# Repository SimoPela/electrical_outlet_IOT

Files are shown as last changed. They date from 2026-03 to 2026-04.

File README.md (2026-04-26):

# Electrical Outlet IoT






ESP32-based environmental monitoring firmware plus a lightweight web dashboard for live MQTT telemetry.

The project is built around an ESP32 running ESP-IDF/FreeRTOS, collecting indoor environment data from multiple sensors (air quality, climate, particulate matter, light spectrum, motion, gas, and audio level), then publishing JSON payloads to MQTT. A Node.js dashboard subscribes to these topics and visualizes live values and trends.

<p align="center">
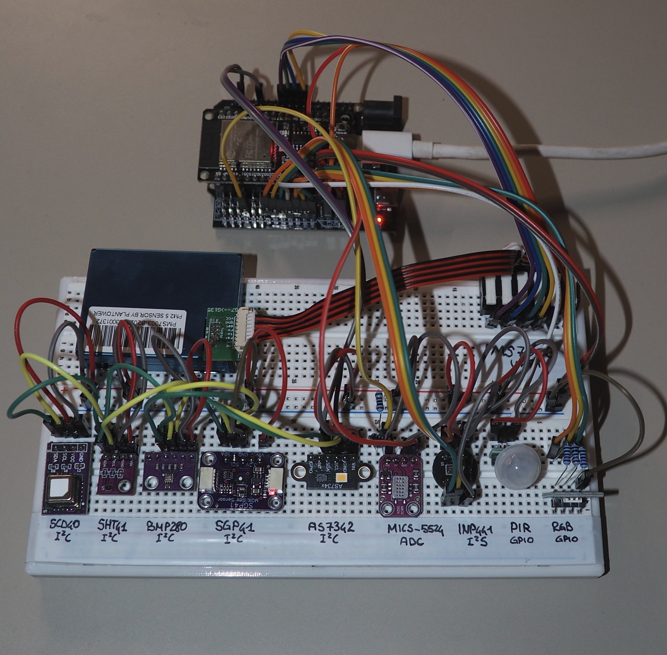
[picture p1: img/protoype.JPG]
Breadboard prototype with ESP32 and environmental sensors
  
</p>

---

## Features

- Multi-sensor acquisition on I2C, UART, I2S, ADC, and GPIO.
- FreeRTOS architecture with dedicated acquisition, audio, system, and communication tasks.
- Shared mutex-protected runtime state (`g_device_state`) with validity/fault flags and timestamps.
- Wi-Fi station mode with automatic reconnect and MQTT telemetry publishing.
- System health evaluation and alarm logic (motion, gas threshold, CO2 level bands).
- Real-time web dashboard (Express + Socket.IO + Chart.js) driven by MQTT messages.

---

## Hardware and Sensors

### Controller
- ESP32 DevKit-style board (`platformio.ini`: `board = esp32dev`, framework `espidf`).

### Sensor set
- `SCD40`: CO2, temperature, humidity (I2C)
- `SHT41`: temperature, humidity (I2C)
- `SGP41`: VOC/NOx indices (I2C, optional compensation from SHT41)
- `BMP280`: pressure, temperature (I2C)
- `AS7341`: 8-channel visible spectrum (I2C)
- `PMS7003`: PM1.0 / PM2.5 / PM10 (UART)
- `MiCS-5524`: gas raw voltage + estimated ppm (ADC)
- `AS312`: PIR motion sensor (GPIO)
- `INMP441`: noise level estimate in dB SPL (I2S)
- RGB status LED (GPIO)

### Default pinout
Defined in `lib/config/include/esp32_pinout.h`:

- I2C SDA/SCL: GPIO `21` / `22`
- PMS7003 TX/RX (sensor side): GPIO `16` / `17`
- PMS7003 SET/RESET: GPIO `4` / `5`
- PIR output: GPIO `27`
- I2S WS/SCK/SD: GPIO `25` / `26` / `33`
- MiCS-5524 ADC: GPIO `34`
- RGB LED R/G/B: GPIO `13` / `12` / `14`

---

## Firmware Architecture

### Boot flow
`app_main()` in `src/main.c` performs:

1. `device_state_init()`
2. `sensor_init_all()`
3. `network_app_init()` and wait for Wi-Fi connection
4. `mqtt_app_start()`
5. Task creation: `acquisition_task`, `audio_task`, `comm_task`, `system_task`

If sensor/network init fails, startup aborts.

### FreeRTOS tasks
Task definitions are configured in `include/task_config.h`.

| Task | Main role | Priority | Stack (words) | Loop period |
|---|---|---:|---:|---:|
| `acquisition_task` | Poll environmental sensors and update shared state | 2 | 4096 | 1000 ms |
| `audio_task` | Read INMP441 and update noise metrics | 2 | 4096 | 500 ms |
| `comm_task` | Publish MQTT system/environment/alarm payloads | 3 | 4096 | 100 ms |
| `system_task` | Evaluate health and alarm state | 4 | 4096 | 100 ms |

The firmware uses periodic polling instead of interrupt-driven sampling for most sensors.
`acquisition_task` runs every 1000 ms and checks per-sensor deadlines (for example 1000 ms, 2000 ms, 2500 ms, 5000 ms depending on the sensor). When a deadline is reached, it reads that sensor, updates local values, then commits a synchronized snapshot to the shared device state.
In parallel, `audio_task` handles the INMP441 capture pipeline at its own cadence, while `system_task` computes health/alarm flags and `comm_task` publishes MQTT payloads from a consistent state snapshot.

```mermaid
flowchart LR
    subgraph RTOS[FreeRTOS Runtime]
        ACQ["acquisition_task (1000 ms loop)\n- deadline-based polling\n- multi-sensor reads"]
        AUD["audio_task (500 ms loop)\n- INMP441 read\n- noise_db update"]
        SYS["system_task (100 ms loop)\n- health checks\n- alarm logic"]
        COM["comm_task (100 ms loop)\n- MQTT publish scheduler"]
    end

    DS[("g_device_state\n(mutex-protected shared snapshot)")]
    BRK["MQTT broker"]

    ACQ -->|"poll sensors + write measurements"| DS
    AUD -->|"write audio metrics"| DS
    SYS <-->|"read/write system flags"| DS
    COM -->|"read snapshot"| DS
    COM -->|"publish JSON payloads"| BRK
```

### Shared runtime state
`lib/device_state/include/device_state.h` defines:

- `g_device_state` (`device_state_t`): all sensor values, validity/fault flags, timestamps, connectivity flags, alarm status.
- `g_device_state_mutex`: protects shared state access.
- `g_sensor_driver_mutex`: serializes sensor driver access and restore operations.

### Health and alarms
Implemented in:
- `lib/health/src/health.c`
- `lib/alarm/src/alarm.c`

Current logic includes:
- degraded mode/system status based on validity/fault/freshness checks,
- motion alarm from PIR,
- gas alarm when MiCS-5524 estimated ppm is above threshold,
- CO2 qualitative level (`optimal`, `good`, `moderate`, `poor`, `very poor`, `critical`).

---

## MQTT Interface

Topic builders are implemented in `lib/mqtt/src/mqtt_topic.c`.

Published topics:

- `devices/<device_id>/telemetry/environment`
- `devices/<device_id>/status/system`
- `devices/<device_id>/event/alarm`

Payload builders are in `lib/mqtt/src/mqtt_payload.c`:

- **Environment payload**: CO2, temperatures, humidities, pressure, VOC/NOx, PM values, light channels, gas values, noise dB.
- **System payload**: `system_ok`, `degraded_mode`, `wifi_connected`, `mqtt_connected`, `status`.
- **Alarm payload**: `as312_alarm`, `mics5524_alarm`, `co2_alarm_level`.

---

## Repository Structure

```text
.
├── src/                    # app_main and FreeRTOS task implementations
├── include/                # task headers and timing/priority configuration
├── lib/
│   ├── config/             # app config template and ESP32 pin mapping
│   ├── sensor_init/        # centralized peripheral/sensor initialization
│   ├── device_state/       # shared state and mutexes
│   ├── network/            # Wi-Fi connection management
│   ├── mqtt/               # topic/payload/publish/client logic
│   ├── health/             # system health checks
│   ├── alarm/              # alarm decision logic
│   ├── inmp441/            # audio wrapper and dB estimate
│   └── ...                 # individual sensor drivers
├── server/                 # Node.js + Socket.IO live dashboard
├── scripts/                # build helper scripts (clangd/toolchain patching)
├── datasheet/              # sensor datasheets
└── platformio.ini          # PlatformIO environment
```

---

## Getting Started

### 1) Firmware (ESP32)

### Prerequisites
- [PlatformIO Core](https://platformio.org/install)
- ESP32 board connected over USB

### Configuration
1. Create/update `lib/config/include/app_config.h` using `lib/config/include/app_config_template.h`.
2. Set:
   - `APP_WIFI_SSID`
   - `APP_WIFI_PASSWORD`
   - `APP_MQTT_BROKER_URI`
   - `APP_MQTT_USERNAME`
   - `APP_MQTT_PASSWORD`
   - `APP_DEVICE_ID`
3. If needed, adjust GPIO mapping in `lib/config/include/esp32_pinout.h`.
4. Update serial upload settings in `platformio.ini` (`upload_port`, optionally `upload_speed`).

### Build, flash, monitor
```bash
pio run
pio run -t upload
pio device monitor -b 115200
```

Other useful commands:
```bash
# clean build
pio run -t clean
# erase flash
pio run -t erase
# generate compiledb database for IDE indexing
pio run -t compiledb
```

### 2) Dashboard server

The dashboard is located in `server/` and subscribes to MQTT topics, then forwards updates to browser clients via Socket.IO.

### Prerequisites
- Node.js 18+ recommended

### Setup
```bash
cd server
npm install
cp .env.example .env
```

Edit `.env`:
- `MQTT_BROKER_URL`
- `MQTT_USERNAME`
- `MQTT_PASSWORD`
- `PORT` (default `3000`)
- `ALARM_ON_MS` (temporary alarm display duration)

### Run
```bash
npm start
```

Open: `http://localhost:3000`

---

## Development Notes

- Build options and monitor/upload defaults are in `platformio.ini`.
- `scripts/update_clangd_toolchain.py` updates `.clangd` include sections after build for better IDE indexing.
- Sensor polling and publish intervals are centralized in `include/task_config.h`.
- Debug logs use ESP-IDF logging macros (`ESP_LOGE/W/I/D`).

---

## Security Notes

- Do not commit real Wi-Fi/MQTT credentials.
- Keep secrets only in local config files (`app_config.h`, `server/.env`) and exclude them from public history.

---

## License

This project is licensed under the Apache License 2.0 (see source headers).

## Authors

- Simone Pelascini
- Aurélien Bollin

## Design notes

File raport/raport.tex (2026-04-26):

\documentclass[11pt,a4paper]{article}
\usepackage[utf8]{inputenc}
\usepackage[T1]{fontenc}
\usepackage[english]{babel}
\usepackage{lmodern}
\usepackage{microtype}
\usepackage{geometry}
\usepackage{graphicx}
\usepackage[table]{xcolor}
\usepackage{booktabs}
\usepackage{longtable}
\usepackage{tabularx}
\usepackage{multirow}
\usepackage{hyperref}
\usepackage{enumitem}
\usepackage{tikz}
\usepackage{fancyhdr}
\usepackage{titlesec}
\usepackage{caption}
\usepackage{setspace}
\usepackage{mdframed}
\usepackage{array}
\usepackage{amsmath}
\usepackage{makecell}
\usepackage{seqsplit}

\usetikzlibrary{arrows.meta,positioning,shapes.geometric}

% --- Brand palette ---
\definecolor{bfhblue}{HTML}{1a3a5c}
\definecolor{bfhaccent}{HTML}{2d6a8f}
\definecolor{tablehdr}{HTML}{e8eef4}
\definecolor{lightgray}{HTML}{f5f7fa}
\definecolor{stategreen}{HTML}{d4edda}
\definecolor{stateyellow}{HTML}{fff3cd}
\definecolor{statered}{HTML}{f8d7da}
\definecolor{stategreentext}{HTML}{155724}
\definecolor{stateyellowtext}{HTML}{856404}
\definecolor{stateredtext}{HTML}{721c24}
\definecolor{infobox}{HTML}{e8f4fd}
\definecolor{infoborder}{HTML}{2d6a8f}

\geometry{margin=2.4cm, top=2.6cm, bottom=2.8cm, headheight=22pt}
\setlength{\parindent}{0pt}
\usetikzlibrary{arrows.meta,positioning,shapes.geometric,shapes.multipart}
%\setlength{\parskip}{6pt}
\hypersetup{
    colorlinks=true,
    linkcolor=bfhblue,
    urlcolor=bfhaccent,
    citecolor=bfhblue,
    pdftitle={RTOS Project Work -- Electrical Outlet IoT},
    pdfauthor={Simone Pelascini, Aurelien Bollin}
}

\captionsetup{font=small, labelfont={bf,color=bfhblue}}

% Section titles
\titleformat{\section}
    {\Large\bfseries\color{bfhblue}}
    {\thesection}{0.75em}{}
    [\vspace{-0.3em}{\color{bfhaccent}\titlerule[0.6pt]}]
\titleformat{\subsection}
    {\large\bfseries\color{bfhblue!85!black}}
    {\thesubsection}{0.6em}{}
\titleformat{\subsubsection}
    {\normalsize\bfseries\color{bfhblue!70!black}}
    {\thesubsubsection}{0.5em}{}
\titlespacing*{\section}{0pt}{1.8ex plus .2ex}{1.1ex plus .1ex}
\titlespacing*{\subsection}{0pt}{1.3ex plus .1ex}{0.7ex plus .1ex}

\setlist{itemsep=0.3ex, topsep=0.6ex}

% Info box style
\mdfdefinestyle{infoboxstyle}{
    backgroundcolor=infobox,
    linecolor=infoborder,
    linewidth=1.2pt,
    leftline=true, rightline=false, topline=false, bottomline=false,
    innerleftmargin=10pt, innerrightmargin=8pt,
    innertopmargin=6pt, innerbottommargin=6pt,
    skipabove=6pt, skipbelow=6pt
}

% Header / footer
\pagestyle{fancy}
\fancyhf{}
\fancyhead[L]{\small\color{bfhblue}\textbf{Electrical Outlet IoT}}
\fancyhead[R]{\small\color{gray}\nouppercase{\leftmark}}
\fancyfoot[C]{%
\small
Bern University of Applied Sciences \textbar{}
Engineering and Computer Science \textbar{}
Electrical Engineering and Information Technology
}
\renewcommand{\headrulewidth}{0.4pt}
\renewcommand{\headrule}{\hbox to\headwidth{\color{bfhaccent}\leaders\hrule height \headrulewidth\hfill}}

\fancypagestyle{plain}{%
  \fancyhf{}
  \fancyfoot[C]{%
  \small
  Bern University of Applied Sciences \textbar{}
  Engineering and Computer Science \textbar{}
  Electrical Engineering and Information Technology
  }
  \renewcommand{\headrulewidth}{0pt}
}

% Helpers
\newcommand{\rowhdr}{\rowcolor{tablehdr}}
\newcommand{\stateImpl}{\cellcolor{stategreen}\textcolor{stategreentext}{\textbf{implemented}}}
\newcommand{\statePartial}{\cellcolor{stateyellow}\textcolor{stateyellowtext}{\textbf{partial}}}
\newcommand{\stateOpen}{\cellcolor{statered}\textcolor{stateredtext}{\textbf{open}}}

% ============================================================
\begin{document}

% ---------- Title page ----------
\begin{titlepage}
    \centering
    \vspace*{0.15cm}
    {\color{bfhblue}\rule{\textwidth}{2.2pt}}
    \vspace{0.55cm}

    {\Large\color{bfhaccent}Bern University of Applied Sciences\par}
    {\normalsize Engineering and Computer Science\par}
    {\normalsize Electrical Engineering and Information Technology\par}

    \vspace{1.2cm}
    {\Huge\bfseries\color{bfhblue}RTOS Project Work\par}
    \vspace{0.45cm}
    {\LARGE\color{bfhblue!80!black}Electrical Outlet IoT\par}
    \vspace{0.35cm}
    {\large Environmental monitoring node on ESP32 with FreeRTOS and MQTT\par}

    \vspace{1.6cm}
    \IfFileExists{../img/protoype.JPG}{%
        %
        \par\vspace{0.3em}
        {\small\color{gray}\textit{Breadboard prototype of the sensor node.}}
    }{%
        \fbox{\parbox{0.60\textwidth}{\centering\vspace{2.2cm}\texttt{../img/protoype.JPG} not found\vspace{2.2cm}}}%
    }

    \vfill
    {\large\textbf{Authors:} Simone Pelascini \quad\textbar\quad Aur\'elien Bollin\par}
    \vspace{0.6cm}
    {\large\textbf{Date:} \today\par}
    \vspace{1cm}
    {\color{bfhblue}\rule{\textwidth}{2pt}}
\end{titlepage}

\cleardoublepage
\pagenumbering{arabic}
\setcounter{page}{1}

\onehalfspacing
\tableofcontents
\newpage

% ============================================================
\section{Summary}
\vspace{10pt}

The \textbf{Electrical Outlet IoT} project is an ESP32-based environmental monitoring node designed to
be integrated into a standard wall-outlet form factor. The motivation behind this project is the growing
demand for \textbf{ambient air quality monitoring} and \textbf{occupancy-aware automation} in residential
and commercial buildings. Poor indoor air quality, driven by CO\textsubscript{2} accumulation,
volatile organic compounds (VOC), particulate matter (PM), and combustible gas, is a largely invisible
health risk. Existing commercial solutions are either too expensive, closed-source, or limited to a single
measurement type.

\vspace{5pt}

This project addresses that gap by combining nine sensors on a single node,
connected to a local MQTT broker for real-time telemetry. The firmware is built on \textit{PlatformIO},
\textit{ESP-IDF}, and \textit{FreeRTOS}, making use of four concurrent tasks that coordinate through
a \textbf{mutex-protected global state structure}. Sensor data is published as JSON payloads
and consumed by a companion Node.js dashboard that renders live charts via \textit{Chart.js}
and pushes updates to browsers via \textit{Socket.IO}.

\vspace{5pt}

The current repository documents breadboard bring-up, firmware architecture, runtime
characterisation, and the web-dashboard edge. The form-factor integration into an actual outlet housing
is left as a future step.

% ============================================================
\section{System Context}
\subsection{Hardware}
\vspace{5pt}

The sensor node is built around an \textbf{ESP32 dual-core 240~MHz} microcontroller (Espressif
\texttt{esp32dev} target). It communicates with nine sensors over five distinct interfaces.
Table~\ref{tab:sensors} summarises the complete sensor inventory.

{\footnotesize
\setlength{\tabcolsep}{4pt}
\renewcommand{\arraystretch}{1.1}

\rowcolors{2}{lightgray}{white}
\setlength\LTleft{0pt}
\begin{longtable}{@{}p{2.3cm}p{2.8cm}p{6cm}p{1.4cm}p{2.5cm}@{}}
\caption{Complete sensor inventory used by the ESP32 node.\label{tab:sensors}}\\
\rowhdr
\textbf{Sensor} & \textbf{Measured quantity} & \textbf{Physical value} & \textbf{Bus} & \textbf{Driver} \\
\midrule
\endhead
SCD40        & CO\textsubscript{2}, T, RH & Concentration, temperature, humidity & I\textsuperscript{2}C & Direct ESP-IDF \\
SHT41        & Temperature, humidity & High-precision T \& RH & I\textsuperscript{2}C & esp-idf-lib \\
SGP41        & VOC, NOx              & Gas indices 0--500 (Sensirion algorithm) & I\textsuperscript{2}C & Custom + GIA \\
BMP280       & Pressure, temperature & Atmospheric P \& T & I\textsuperscript{2}C & esp-idf-lib \\
AS7341       & Light spectrum        & 8-channel F1--F8 basic counts & I\textsuperscript{2}C & k0i05/esp\_as7341 \\
PMS7003      & Particulate matter    & PM1.0, PM2.5, PM10 [\textmu g/m\textsuperscript{3}] & UART & Custom wrapper \\
MiCS-5524    & Combustible gas       & Voltage [V], heuristic CO [ppm] & ADC & Custom \\
AS312        & PIR motion            & Motion detected (boolean) & GPIO & Custom \\
INMP441      & Ambient noise         & Sound pressure level [dB~SPL] & I\textsuperscript{2}S & Custom DSP \\
\bottomrule
\end{longtable}
\rowcolors{2}{}{}
}

\newpage

\subsection{System actors and data paths}
\vspace{5pt}

The system involves the following actors:
\begin{itemize}[leftmargin=*]
    \item \textbf{Sensor node}: ESP32 (\texttt{esp32dev}), firmware in \texttt{src/} and \texttt{lib/}.
          Samples all sensors on software-defined deadlines, aggregates readings into a shared
          in-memory state, and transmits them via Wi-Fi.
    \item \textbf{Wi-Fi / TCP}: the node connects as a Wi-Fi station; all MQTT traffic flows over
          a standard TCP connection to the broker.
    \item \textbf{MQTT broker}: any standard broker (e.g.\ Mosquitto) reachable on the LAN.
          Credentials and URI are configured in \texttt{lib/config/include/app\_config.h}.
    \item \textbf{Node.js dashboard}: an optional \texttt{server/} application that subscribes to
          all device topics and renders live charts in the browser via Socket.IO and Chart.js.
    \item \textbf{Third-party consumers}: any MQTT subscriber can access the JSON payloads
          independently of the dashboard.
\end{itemize}

\vspace{5pt}
\subsection{MQTT topics}
\vspace{5pt}

All publications follow the hierarchy \texttt{devices/\textless device\_id\textgreater /}
where \texttt{device\_id} is set by \texttt{\seqsplit{APP\_DEVICE\_ID}}:

\begin{itemize}[leftmargin=*]
    \item \texttt{telemetry/environment} (QoS~0) --- full sensor snapshot:
          CO\textsubscript{2}, T, RH from SCD40 and SHT41, atmospheric pressure, VOC/NOx indices,
          PM1.0/2.5/10, 8-channel light array, gas voltage and ppm, noise level in dB~SPL.
          Published every \textbf{1~s}.
    \item \texttt{\seqsplit{status/system}} (QoS~1, retain) --- system health flags:
          \texttt{\seqsplit{system\_ok}}, \texttt{\seqsplit{degraded\_mode}}, \texttt{\seqsplit{wifi\_connected}},
          \texttt{\seqsplit{mqtt\_connected}}. Published every \textbf{10~s} and immediately on reconnect.
    \item \texttt{\seqsplit{event/alarm}} (QoS~1) --- event-driven alert:
          \texttt{\seqsplit{as312\_alarm}} (motion), \texttt{\seqsplit{mics5524\_alarm}} (gas threshold exceeded),
          \texttt{\seqsplit{co2\_alarm\_level}} (IDA-inspired 6-level classification).
          Published only on the \textbf{rising edge} of each alarm flag.
\end{itemize}

\vspace{5pt}
\subsection{Web dashboard}
\vspace{5pt}

The companion dashboard runs on Node.js (\texttt{server/public/server.js}) and uses the
\texttt{\seqsplit{express}}, \texttt{\seqsplit{mqtt}}, \texttt{\seqsplit{socket.io}}, and \texttt{\seqsplit{dotenv}} packages. It subscribes
to the wildcard patterns \texttt{\seqsplit{devices/+/telemetry/environment}},
\texttt{\seqsplit{devices/+/status/system}}, and \texttt{\seqsplit{devices/+/event/alarm}}, merges incoming payloads
into a per-device state object, and forwards it to all connected browsers in real time.
Configuration is via a \texttt{.env} file (\texttt{\seqsplit{MQTT\_BROKER\_URL}}, optional credentials, \texttt{\seqsplit{PORT}}).

\newpage

% ============================================================
\section{Requirements}\label{sec:requirements}
\vspace{10pt}

Requirements are written from the user perspective and are traceable to implementation files.
The \textbf{State} column uses colour coding:
\colorbox{stategreen}{\textcolor{stategreentext}{implemented}},
\colorbox{stateyellow}{\textcolor{stateyellowtext}{partial}}, or
\colorbox{statered}{\textcolor{stateredtext}{open}}.

{\footnotesize
\setlength{\tabcolsep}{4pt}
\renewcommand{\arraystretch}{1.1}

\rowcolors{2}{lightgray}{white}
\setlength\LTleft{0pt}
\begin{longtable}{@{}>{\bfseries}p{0.9cm}p{11.6cm}p{3.0cm}@{}}
\caption{System requirements and current implementation status.\label{tab:requirements}}\\
\rowhdr
\multicolumn{1}{@{}l}{\textbf{ID}} & \textbf{Requirement (user perspective)} & \textbf{State} \\
\midrule
\endhead
R1 & The system shall boot, initialise all peripherals, create four FreeRTOS tasks, and reach a
     fully operational state without a fatal error within 20~s of power-on. & \stateImpl \\
R2 & The system shall connect to the configured Wi-Fi network within 15~s; on disconnect it shall
     retry up to \texttt{APP\_WIFI\_MAX\_RETRY} times automatically. & \stateImpl \\
R3 & The system shall publish a JSON environment payload to the MQTT broker at least every 1~s
     and a system-status payload every 10~s when connected. & \stateImpl \\
R4 & The system shall publish an alarm event payload on the rising edge of a motion or gas alarm,
     without missing edges caused by task jitter. & \stateImpl \\
R5 & All concurrent accesses to \texttt{g\_device\_state} shall be serialised by a FreeRTOS
     mutex (\texttt{g\_device\_state\_mutex}) with no unbounded blocking. & \stateImpl \\
R6 & All nine integrated sensors shall be polled within their specified deadlines without one
     slow sensor blocking another. & \stateImpl \\
R7 & The system shall report an estimated ambient noise level (\texttt{noise\_db}) in dB~SPL;
     absolute accuracy relative to a calibrated sound-level meter is not guaranteed without
     field calibration of \texttt{INMP441\_SPL\_OFFSET\_DB}. & \statePartial \\
R8 & Stack high-water mark and heap usage shall be logged and reported for all tasks over at
     least 10~minutes of continuous operation. & \stateImpl \\
R9 & Automated unit tests shall cover MQTT payload builders and sensor supervision logic. & \stateOpen \\
R10 & The system shall attempt automatic sensor restoration (re-initialisation and recovery) after
      a detected sensor crash, with bounded retries and fault reporting if recovery fails. & \stateOpen \\
\bottomrule
\end{longtable}
\rowcolors{2}{}{}
}

\newpage

% ============================================================
\section{Design}
\subsection{Boot sequence}
\vspace{5pt}

At startup, \texttt{app\_main} (in \texttt{src/main.c}) executes the following ordered steps.
All critical steps abort the system on failure; non-critical sensor failures are logged as
warnings and allow the system to continue in degraded mode.

\begin{enumerate}[leftmargin=*, label=\textbf{\arabic*.}]
    \item \textbf{\texttt{device\_state\_init()}} --- zero-initialises \texttt{g\_device\_state}
          and creates the two FreeRTOS mutexes (\texttt{g\_device\_state\_mutex} and
          \texttt{g\_sensor\_driver\_mutex}).
    \item \textbf{\texttt{sensor\_init\_all()}} --- initialises hardware peripherals in order:
          ADC unit~1, I\textsuperscript{2}S channel, I\textsuperscript{2}C bus, UART~2, then
          each sensor driver. Critical peripherals abort on failure; sensors warn and continue.
    \item \textbf{\texttt{network\_app\_init()}} --- initialises NVS, netif, Wi-Fi driver, and
          starts the connection; registers event handlers for \texttt{WIFI\_EVENT} and
          \texttt{IP\_EVENT}.
    \item \textbf{\texttt{\seqsplit{network\_app\_wait\_until\_connected(15000)}}} --- blocks up to 15~s
          waiting for \texttt{\seqsplit{APP\_WIFI\_CONNECTED\_BIT}}; aborts if the bit is not set.
    \item \textbf{\texttt{mqtt\_app\_start()}} --- creates the ESP-IDF MQTT client, registers
          the event handler, and starts the client task.
    \item \textbf{Task creation} --- \texttt{xTaskCreate} is called for each of the four tasks;
          any allocation failure aborts immediately.
\end{enumerate}

\newpage

\subsection{FreeRTOS task architecture}

The firmware is decomposed into four independent FreeRTOS tasks. All tasks use
\texttt{vTaskDelayUntil} for deterministic loop periods and \texttt{xSemaphoreTake} /
\texttt{xSemaphoreGive} for exclusive access to the shared state. Table~\ref{tab:tasks} summarises
the static parameters.

{\footnotesize
\setlength{\tabcolsep}{4pt}
\renewcommand{\arraystretch}{1.1}

\rowcolors{2}{lightgray}{white}
\setlength\LTleft{0pt}
\begin{longtable}{@{}p{3.1cm}p{7.6cm}ccp{2.0cm}@{}}
\caption{Static configuration of the four FreeRTOS tasks.\label{tab:tasks}}\\
\rowhdr
\textbf{Task} & \textbf{Responsibility} & \textbf{Pri.} & \textbf{Stack (w)} & \textbf{Period} \\
\midrule
\endhead
\texttt{acquisition\_task} & Polls all sensors on individual software deadlines; writes measured
  values, validity flags, and fault flags into \texttt{g\_device\_state} under the mutex. & 2 & 4096 & 1000~ms \\
\texttt{audio\_task} & DMA-reads one audio block from the INMP441 via I\textsuperscript{2}S,
  computes AC-RMS SPL, and updates \texttt{noise\_db} in the shared state. & 2 & 4096 & 500~ms \\
\texttt{comm\_task} & Snapshots the shared state and drives the MQTT publish schedule:
  environment telemetry at 1~s, system status at 10~s, and alarm events on rising edge. & 3 & 4096 & 100~ms \\
\texttt{system\_task} & Reads the shared state snapshot, evaluates per-sensor health checks
  (staleness, fault, validity) and alarm logic, then writes derived system flags back. & 4 & 4096 & 100~ms \\
\bottomrule
\end{longtable}
\rowcolors{2}{}{}
}

\vspace{5pt}
\begin{mdframed}[style=infoboxstyle]
\textbf{Design pattern --- local state before commit.}
Each task maintains a task-local state structure initialised to zero. Sensor readings and flags are
written to this local copy first; only when a consistent update is ready is the mutex acquired and
the global \texttt{g\_device\_state} updated in a single block-copy. This minimises the critical
section duration and avoids partially-updated state being observed by other tasks.
\end{mdframed}

\subsection{Sensor polling intervals}

Sensors inside \texttt{\seqsplit{acquisition\_task}} are polled on independent software timers derived from
\texttt{\seqsplit{xTaskGetTickCount()}}. Each sensor deadline is checked at every 1000~ms task tick; the
sensor is read only when \texttt{now - last\_read \(\geq\) interval}. This means a single slow
sensor (e.g.\ PMS7003) does not delay faster ones (e.g.\ AS312).

\vspace{8pt}

{\footnotesize
\setlength{\tabcolsep}{4pt}
\renewcommand{\arraystretch}{1.1}

\noindent
\captionof{table}{Sensor polling intervals and interfaces used by the firmware.\label{tab:polling_intervals}}
\begin{tabularx}{\textwidth}{@{}lXrr@{}}
\toprule
\rowhdr
\textbf{Sensor} & \textbf{Physical quantity} & \textbf{Interface} & \textbf{Interval} \\
\midrule
AS312  & PIR motion                         & GPIO                          & 1000~ms \\
MiCS-5524 & Combustible gas (CO heuristic)  & ADC                           & 1000~ms \\
SGP41  & VOC index, NOx index               & I\textsuperscript{2}C         & 1000~ms \\
AS7341 & 8-channel light spectrum           & I\textsuperscript{2}C         & 1000~ms \\
SHT41  & Temperature, humidity              & I\textsuperscript{2}C         & 2000~ms \\
BMP280 & Atmospheric pressure               & I\textsuperscript{2}C         & 2000~ms \\
SCD40  & CO\textsubscript{2}, temperature, humidity & I\textsuperscript{2}C  & 2500~ms \\
PMS7003 & PM1.0, PM2.5, PM10               & UART                          & 5000~ms \\
INMP441 & Noise level (dB SPL)             & I\textsuperscript{2}S (audio\_task) & 500~ms \\
\bottomrule
\end{tabularx}
}

\newpage

\subsection{System supervision and alarm logic}

\texttt{system\_task} implements two independent modules:

\textbf{Health module} (\texttt{lib/health/}): after a 45~s cold-start window, each sensor
is checked for three conditions: (1) the validity flag is \texttt{false}, (2) the fault flag is
\texttt{true}, or (3) the timestamp age exceeds a per-sensor timeout (45~s for all sensors).
Any failing check sets \texttt{degraded\_mode = true} and the sensor-specific \texttt{degraded\_*}
flag.

\textbf{Alarm module} (\texttt{lib/alarm/}): three independent sub-checks evaluate
(1)~motion from the AS312 PIR, (2)~gas concentration from MiCS-5524 against a 5000~ppm threshold,
and (3)~CO\textsubscript{2} from SCD40 classified into six levels (Optimal / Good / Moderate /
Poor / Very Poor / Critical) following IDA and ASHRAE~62.1-inspired thresholds.

\subsection{System context diagram}
\vspace{5pt}

\begin{figure}[!htbp]
\centering
\begin{tikzpicture}[
    scale=0.82,
    transform shape,
    node distance=9mm and 18mm,
    task/.style={
        draw=bfhblue!70!black,
        rounded corners=2pt,
        align=center,
        minimum width=58mm,
        minimum height=10mm,
        fill=lightgray,
        font=\small
    },
    state/.style={
        draw=bfhblue!70!black,
        cylinder,
        shape border rotate=90,
        aspect=0.25,
        align=center,
        minimum width=42mm,
        minimum height=13mm,
        fill=white,
        font=\small
    },
    ext/.style={
        draw=bfhaccent!80!black,
        rounded corners=2pt,
        align=center,
        minimum width=32mm,
        minimum height=10mm,
        fill=lightgray,
        font=\small
    },
    arrow/.style={
        -{Latex[length=2.2mm]},
        thick,
        color=bfhblue!75!black
    },
    label/.style={
        font=\scriptsize,
        fill=white,
        inner sep=1.5pt,
        text=bfhaccent!80!black
    }
]

% Sensors block
\node[ext] (sensors)
{\textbf{Sensors}\\[-1pt]\scriptsize 9 sensors};

% Tasks
\node[task, below right=18mm and 30mm of sensors] (acq)
{\texttt{acquisition\_task}\\[-1pt]\scriptsize 1000~ms prio 2};

\node[task, below=18mm of acq] (audio)
{\texttt{audio\_task}\\[-1pt]\scriptsize 500~ms prio 2};

\node[task, below=18mm of audio] (system)
{\texttt{system\_task}\\[-1pt]\scriptsize 100~ms prio 4};

\node[task, below=18mm of system] (comm)
{\texttt{comm\_task}\\[-1pt]\scriptsize 100~ms prio 3};

% Shared state and MQTT
\node[state, right=35mm of audio] (devstate)
{\texttt{g\_device\_state}\\[-1pt]\scriptsize mutex-protected};

\node[ext, below right=18mm and 38mm of comm] (mqtt)
{\textbf{MQTT broker}\\[-1pt]\scriptsize Wi-Fi / TCP};

% Connections
\draw[arrow] (sensors.east) -- node[label, above]
{GPIO/I\textsuperscript{2}C/ADC/UART/I\textsuperscript{2}S}
(acq.west);

\draw[arrow] (acq.east) -- node[label, above]
{poll sensors + write measurements}
(devstate.north west);

\draw[arrow] (audio.east) -- node[label, above]
{write audio metrics}
(devstate.west);

\draw[arrow] (system.east) -- node[label, above]
{read/write system flags}
(devstate.south west);

\draw[arrow] (devstate.south) |- node[label, near start, right]
{read snapshot}
(comm.east);

\draw[arrow] (comm.east) -- node[label, below]
{publish JSON payloads}
(mqtt.west);

\end{tikzpicture}

\caption{System context diagram showing sensors, FreeRTOS tasks, the mutex-protected shared state,
and the MQTT broker used for publishing telemetry, status, and alarm messages.}
\end{figure}

\newpage

\subsection{UML task interaction diagram}

\begin{figure}[!htbp]
\centering
\IfFileExists{../img/uml_4task.png}{%
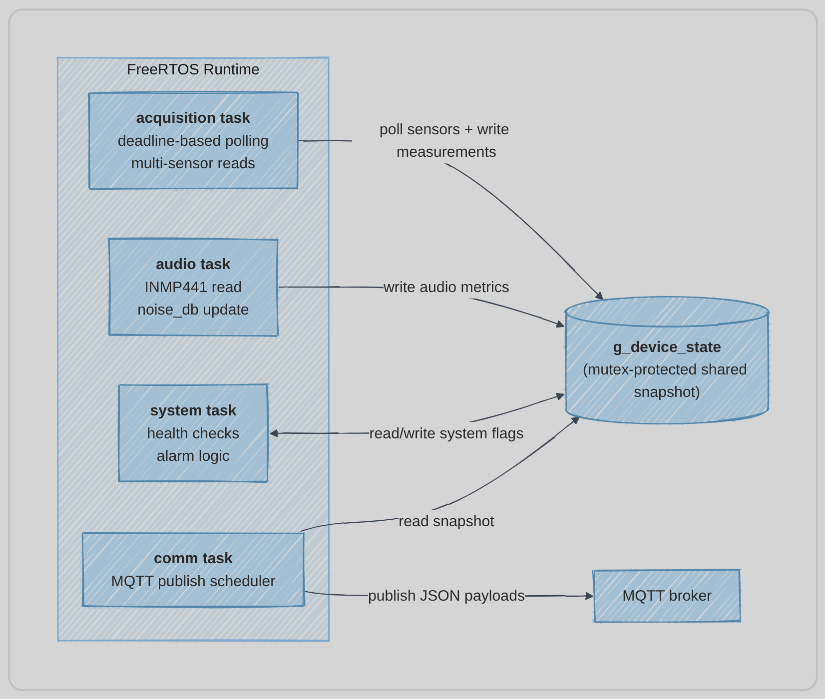
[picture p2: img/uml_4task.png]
    %
}{%
    \fbox{\parbox{0.88\textwidth}{\centering\vspace{1.8cm}
    \texttt{../img/uml\_4task.png} not found\vspace{1.8cm}}}%
}
\caption{UML activity/sequence diagram of the four FreeRTOS tasks and their interactions
with \texttt{g\_device\_state} and the MQTT client.}
\end{figure}

\subsection{Acquisition polling flow}

\begin{figure}[!htbp]
\centering
\begin{tikzpicture}[
    scale=0.82,
    transform shape,
    node distance=6mm,
    proc/.style={draw=bfhblue!65, rounded corners=2pt, align=center,
                 minimum width=58mm, minimum height=7mm, fill=white, font=\small},
    dec/.style={draw=bfhaccent, diamond, aspect=2.3, align=center,
                inner sep=1pt, fill=lightgray, font=\small},
    arrow/.style={-{Latex[length=1.8mm]}, thick, color=bfhblue!70!black}
]
\node[proc] (loop) {\textbf{Task tick} (every 1000~ms via \texttt{vTaskDelayUntil})};
\node[dec, below=of loop] (due) {Sensor deadline\\ elapsed?};
\node[proc, below=of due] (read) {Read sensor $\rightarrow$ local state};
\node[proc, below=of read] (flag) {Update validity / fault flags};
\node[proc, below=of flag] (commit) {Acquire mutex $\rightarrow$ copy to \texttt{g\_device\_state} $\rightarrow$ release};
\node[proc, right=22mm of read] (skip) {Skip (next tick)};

\draw[arrow] (loop) -- (due);
\draw[arrow] (due) -- node[left, font=\scriptsize] {yes} (read);
\draw[arrow] (read) -- (flag);
\draw[arrow] (flag) -- (commit);
\draw[arrow] (commit.east) -| (skip.south);
\draw[arrow] (due.east) -- node[above, font=\scriptsize] {no} (skip.north);
\draw[arrow] (skip.north east) -- ++(6mm,0) |- (loop.east);
\end{tikzpicture}
\caption{Deadline-driven polling inside \texttt{acquisition\_task}: each sensor has its own
independent timer; skipped sensors do not block the loop.}
\end{figure}

\newpage

% ============================================================
\section{Runtime Statistics}\label{sec:runtime}

\subsection{Methodology}
\vspace{5pt}

Runtime measurements were collected from the ESP32 serial log using the helper functions
\texttt{logTaskStackHeapUsage()} and \texttt{logTaskAlive()}, defined in
\texttt{src/task\_config.c}. Each task logs its own stack high-water mark and the system-wide
heap state every \textbf{10~s} of wall-clock time. The measurements span approximately
\textbf{10~minutes} of continuous operation under normal conditions (all sensors active,
Wi-Fi connected, MQTT publishing running). Raw data is archived in
\texttt{raport/project\_info/stack\_heap.txt}.

Stack usage percentage is computed as:
\[
\text{Stack Usage} = \frac{\text{words used (high-water mark)}}{\text{stack allocated (words)}} \times 100\%
\]
where \emph{words used} = allocated $-$ high-water mark remaining (reported by
\texttt{\seqsplit{uxTaskGetStackHighWaterMark()}}; 1~word~= 4~bytes on ESP32).

\subsection{Stack usage per task}

\vspace{5pt}
{\footnotesize
\setlength{\tabcolsep}{4pt}
\renewcommand{\arraystretch}{1.1}

\rowcolors{2}{lightgray}{white}
\setlength\LTleft{0pt}
\begin{longtable}{@{}p{3.0cm}p{1.5cm}p{2.5cm}p{2.5cm}p{2.5cm}p{2.5cm}@{}}
\caption{Measured stack usage per FreeRTOS task over the runtime window.\label{tab:stack_usage}}\\
\rowhdr
\textbf{Task} & \textbf{Pri.} &
\makecell[c]{\textbf{Stack}\\\textbf{alloc. (w)}} &
\makecell[c]{\textbf{Stack used}\\\textbf{(HWM, w)}} &
\makecell[c]{\textbf{Usage}\\\textbf{(\%)}} &
\makecell[c]{\textbf{Avg. CPU}\\\textbf{(\%)}} \\
\midrule
\endhead
\texttt{acquisition\_task} & 2 & 4096 & 2532 & 61.8\% & n/m \\
\texttt{audio\_task}       & 2 & 4096 & 2124 & 51.9\% & n/m \\
\texttt{comm\_task}        & 3 & 4096 & 2812 & 68.7\% & n/m \\
\texttt{system\_task}      & 4 & 4096 & 2352 & 57.4\% & n/m \\
\bottomrule
\end{longtable}
\rowcolors{2}{}{}
}
{\small\textit{n/m = not measured (FreeRTOS runtime stats counter not enabled in this build).}}

\medskip
\begin{mdframed}[style=infoboxstyle]
\textbf{Stack analysis.}
The highest consumer is \texttt{comm\_task} (68.7\%), followed by \texttt{acquisition\_task}
(61.8\%). Even the worst case leaves \textbf{1284~words (5136~bytes) of free stack headroom}
on \texttt{comm\_task}, well above the ESP-IDF recommended minimum of 512~bytes. No stack
overflow was observed during the measurement window. All four stacks are sized safely at the
current feature set; if JSON payload building or additional sensors are added,
\texttt{comm\_task} should be monitored first.
\end{mdframed}

\newpage

\subsection{Heap usage over time}

The heap figures below are system-wide (MALLOC\_CAP\_8BIT pool, total $\approx$~290~KB).
``Min free'' is the all-time minimum free heap reported by
\texttt{heap\_caps\_get\_minimum\_free\_size}, which is the most conservative safety margin.

\vspace{5pt}
{\footnotesize
\setlength{\tabcolsep}{4pt}
\renewcommand{\arraystretch}{1.1}

\rowcolors{2}{lightgray}{white}
\setlength\LTleft{0pt}
\begin{longtable}{@{}p{2.6cm}p{2.3cm}p{2.3cm}p{2.5cm}p{1.5cm}p{3.5cm}@{}}
\caption{System heap usage at three measurement windows.\label{tab:heap}}\\
\rowhdr
\textbf{Window} &
\textbf{Used (B)} &
\textbf{Free (B)} &
\textbf{Min free (B)} &
\textbf{Usage} &
\textbf{Notes} \\
\midrule
\endhead
$\sim$10~s  & 107\,460 & 183\,116 & 176\,968 & 37.0\% & Post-boot steady state \\
$\sim$1~min & 107\,452 & 183\,124 & 176\,968 & 37.0\% & Stable; marginal drift \\
$\sim$10~min & 107\,432 & 183\,144 & 176\,968 & 37.0\% & Stable baseline \\
Peak (transient) & 108\,992 & 181\,584 & 176\,968 & 37.5\% & Acquisition spike \\
\bottomrule
\end{longtable}
\rowcolors{2}{}{}

}

\vspace{5pt}
\begin{mdframed}[style=infoboxstyle]
\textbf{Heap analysis.}
Heap usage is highly stable at approximately \textbf{37\%} of the total $\approx$290~KB pool,
leaving a comfortable \textbf{63\% free} ($\approx$183~KB) during steady-state operation.
The minimum-free-ever figure of \textbf{176\,968~B} ($\approx$173~KB) confirms that even
transient allocation peaks (up to 108\,992~B used, observed periodically during
\texttt{acquisition\_task} sensor reads) do not threaten memory safety.
Importantly, the baseline heap usage \emph{decreased} slightly over 10~minutes (from 107\,460~B
to 107\,432~B), indicating that there are \textbf{no measurable memory leaks} over the
observation window.
\end{mdframed}

\newpage

% ============================================================
\section{File Structure}
\vspace{10pt}

The repository follows the PlatformIO convention with a \texttt{src/} entry point, a
\texttt{lib/} folder for reusable modules, and a top-level \texttt{include/} for headers
shared across tasks. Each library module lives in its own subdirectory with an \texttt{include/}
header folder and a \texttt{src/} implementation folder, making cross-compilation units and
Doxygen generation straightforward.

\vspace{5pt}
{\footnotesize
\setlength{\tabcolsep}{4pt}
\renewcommand{\arraystretch}{1.1}

\rowcolors{2}{lightgray}{white}
\begin{longtable}{@{}p{3.5cm}p{12.2cm}@{}}
\caption{Repository file structure and module responsibilities.\label{tab:file_structure}}\\
\rowhdr
\textbf{Path} & \textbf{Purpose} \\
\midrule
\endhead
\texttt{src/} & Application entry point (\texttt{main.c}) and the four FreeRTOS task implementations:
  \texttt{acquisition\_task.c}, \texttt{audio\_task.c}, \texttt{comm\_task.c},
  \texttt{system\_task.c}. Also contains \texttt{task\_config.c} (stack/heap logging helpers)
  and \texttt{idf\_component.yml} (managed component manifest). \\
\texttt{include/} & Shared task headers (\texttt{*\_task.h}); \texttt{task\_config.h} defining
  stack sizes, task priorities, sensor polling intervals, and MQTT publish cadences. \\
\texttt{lib/config/} & \texttt{app\_config\_template.h} (Wi-Fi, MQTT, QoS, device ID constants)
  and \texttt{esp32\_pinout.h} (GPIO/peripheral pin assignments). \\
\texttt{lib/device\_state/} & Global \texttt{g\_device\_state} struct and the two FreeRTOS
  mutexes; all sensor values, timestamps, validity/fault flags, and system flags. \\
\texttt{lib/network/} & Wi-Fi station init (\texttt{network\_app.c}): NVS, netif, event handlers,
  reconnect logic, and the connection-ready event group. \\
\texttt{lib/mqtt/} & Four modules: \texttt{mqtt\_app} (client lifecycle), \texttt{mqtt\_topic}
  (topic string builders), \texttt{mqtt\_payload} (JSON serialisers),
  \texttt{mqtt\_publish} (high-level publish API). \\
\texttt{lib/sensor\_init/} & Peripheral bring-up: \texttt{adc\_init}, \texttt{i2s\_init},
  \texttt{uart\_init} (individual units), and \texttt{sensor\_init} (orchestrates all). \\
\texttt{lib/} (drivers) & One folder per sensor: \texttt{scd40}, \texttt{sht41}, \texttt{sgp41},
  \texttt{bmp280}, \texttt{as7341}, \texttt{pms7003}, \texttt{mics5524}, \texttt{as312},
  \texttt{inmp441}. Plus \texttt{health} (supervision), \texttt{alarm} (event logic),
  \texttt{rgbled} (status LED). \\
\texttt{lib/sgp41/include/} & Also contains Sensirion's BSD-3 Gas Index Algorithm header
  (\texttt{sensirion\_gas\_index\_algorithm.h}). \\
\texttt{server/} & Node.js dashboard: \texttt{public/server.js} (MQTT subscriber +
  Socket.IO relay), \texttt{app.js}, \texttt{index.html}, \texttt{style.css},
  \texttt{package.json}. \\
\texttt{scripts/} & \texttt{update\_clangd\_toolchain.py}: PlatformIO post-build hook that
  patches \texttt{.clangd} with the correct ESP-IDF include paths for IDE support. \\
\texttt{platformio.ini} & Build configuration: \texttt{esp32dev} target, ESP-IDF framework,
  4~MB flash, 115200~baud monitor, post-build extra script. \\
\texttt{raport/} & This report (\texttt{raport.tex}), the BFH template PDF,
  and \texttt{project\_info/} with raw measurement logs. \\
\bottomrule
\end{longtable}
\rowcolors{2}{}{}

}

\newpage
% ============================================================
\section{User Manual}
\vspace{10pt}

\begin{mdframed}[style=infoboxstyle]
\textbf{Prerequisite:} the ESP32 has already been flashed with the firmware.
You need a Wi-Fi network and an MQTT broker (e.g.\ Mosquitto) reachable on the same LAN.
\end{mdframed}

\subsection{Step 1 --- Configure credentials}

Open \texttt{lib/config/include/app\_config.h} and fill in your values:

\begin{verbatim}
#define APP_WIFI_SSID        "YourNetworkSSID"
#define APP_WIFI_PASSWORD    "YourNetworkPassword"
#define APP_MQTT_BROKER_URI  "mqtt://192.168.1.10"   // broker IP
#define APP_DEVICE_ID        "esp32_node_01"         // unique ID
\end{verbatim}

Leave \texttt{APP\_MQTT\_USERNAME} and \texttt{APP\_MQTT\_PASSWORD} empty if your broker has no
authentication. Rebuild and re-flash after editing this file.

\subsection{Step 2 --- Flash and monitor}

From the repository root, run:

\begin{verbatim}
# Build, upload, and open serial monitor (115200 baud)
pio run -t upload && pio device monitor -b 115200
\end{verbatim}

If the serial port is not detected automatically, add \texttt{upload\_port = /dev/ttyUSB0}
(or the appropriate port) to \texttt{platformio.ini}.

\subsection{Step 3 --- Verify boot sequence}

Watch the serial output. A successful startup prints, in order:

\begin{enumerate}[leftmargin=*, label=\textbf{\arabic*.}]
    \item \texttt{[MAIN] System booting...}
    \item \texttt{[MAIN] Sensors initialized successfully}
    \item \texttt{[MAIN] Wi-Fi connected successfully}
    \item \texttt{[MAIN] Starting MQTT}
    \item \texttt{MQTT\_APP: MQTT client started}
    \item \texttt{[MAIN] All tasks started}
\end{enumerate}

If any step fails, the system prints an error and calls \texttt{abort()}. Check credentials
(\texttt{app\_config.h}), broker reachability (ping from the same subnet), and GPIO wiring.

\newpage
\subsection{Step 4 --- Subscribe to MQTT topics}

Use any MQTT client to verify the data stream. Example with \texttt{mosquitto\_sub}:

\begin{verbatim}
# All topics for this device
mosquitto_sub -h 192.168.1.10 -t "devices/esp32_node_01/#" -v

# Environment telemetry only
mosquitto_sub -h 192.168.1.10 \
  -t "devices/esp32_node_01/telemetry/environment" -v
\end{verbatim}

You should see a new JSON payload roughly every second on the environment topic.

\subsection{Step 5 --- Start the web dashboard (optional)}

\begin{verbatim}
cd server
npm install                    # first run only
cp .env.example .env           # create local config
\end{verbatim}

Edit \texttt{.env} and set \texttt{MQTT\_BROKER\_URL=mqtt://192.168.1.10} (and
\texttt{PORT} if needed), then:

\begin{verbatim}
npm start
\end{verbatim}

Open \texttt{http://localhost:3000} (or the configured port) in a browser. Live charts for all
sensor channels update automatically via Socket.IO.

\subsection{Troubleshooting}

\begin{itemize}[leftmargin=*]
    \item \textbf{Wi-Fi fails}: verify SSID/password in \texttt{app\_config.h}; check that the
          access point uses WPA2-PSK.
    \item \textbf{MQTT fails}: ping the broker from the LAN; ensure \texttt{APP\_MQTT\_BROKER\_URI}
          starts with \texttt{mqtt://} and uses the correct IP and port (default 1883).
    \item \textbf{Sensor missing from payload}: check wiring against \texttt{esp32\_pinout.h};
          the \texttt{degraded\_mode} flag in \texttt{status/system} will be \texttt{true}
          after 45~s if a sensor stops responding.
    \item \textbf{Noise level seems wrong}: the \texttt{INMP441\_SPL\_OFFSET\_DB} constant in
          \texttt{\seqsplit{lib/inmp441/src/inmp441\_w.c}} can be adjusted. Compare the reported
          \texttt{noise\_db} against a calibrated sound-level meter in a known environment and
          set \texttt{offset = L\_meter - L\_firmware}.
\end{itemize}

\newpage
% ============================================================
\section{Version control}
\vspace{10pt}
{\footnotesize
\setlength{\tabcolsep}{4pt}
\renewcommand{\arraystretch}{1.1}

\rowcolors{2}{lightgray}{white}
\setlength\LTleft{0pt}
\begin{longtable}{@{}p{1.0cm}p{2.2cm}p{10.6cm}p{1.5cm}@{}}
\caption{Document revision history.\label{tab:version_history}}\\
\rowhdr
\textbf{Ver.} & \textbf{Date} & \textbf{Description} & \textbf{Author} \\
\midrule
\endhead
0.1 & 2026-03-18 & Initial RTOS template alignment; basic structure and task overview. & S.\ / A. \\
0.2 & 2026-03-21 & Sensor integration notes; first version of requirements table. & S.\ / A. \\
0.3 & 2026-04-06 & Architecture refresh: context diagram, acquisition flowchart, TODO metrics. & S.\ / A. \\
0.4 & 2026-04-06 & Full English report; layout refresh; MQTT/dashboard/scripts sync with repo. & S.\ / A. \\
0.5 & 2026-04-24 & Runtime statistics filled with measured stack/heap values from 10-min logs. & S.\ / A. \\
1.0 & 2026-04-24 & Final report: sensor table, analysis boxes, improved design section,
                   UML diagram, extended user manual, troubleshooting guide. & S.\ / A. \\
\bottomrule
\end{longtable}
\rowcolors{2}{}{}
}
\vspace{1.2em}
\noindent\textit{Firmware and tools are licensed under the Apache~2.0 License unless noted
otherwise in individual file headers. The Sensirion Gas Index Algorithm is licensed under
BSD~3-Clause.}

\end{document}

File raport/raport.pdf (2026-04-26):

## Bern University of Applied Sciences

Engineering and Computer Science Electrical Engineering and Information Technology

# RTOS Project Work

## Electrical Outlet IoT

Environmental monitoring node on ESP32 with FreeRTOS and MQTT


Breadboard prototype of the sensor node.

Authors: Simone Pelascini | Aurélien Bollin

Date: April 26, 2026

Electrical Outlet IoT | Contents

## Contents

1 Summary | 2
2 System Context | 2
3 Requirements | 4
4 Design | 5
5 Runtime Statistics | 9
6 File Structure | 11
7 User Manual | 12
8 Version control | 14
Bern University of Applied Sciences | Engineering and Computer Science | Electrical Engineering and
Information Technology

Electrical Outlet IoT | 2 System Context

## 1 Summary

The Electrical Outlet IoT project is an ESP32-based environmental monitoring node designed to be integrated into a standard wall-outlet form factor. The motivation behind this project is the growing demand for ambient air quality monitoring and occupancy-aware automation in residential and commercial buildings. Poor indoor air quality, driven by CO2 accumulation, volatile organic compounds (VOC), particulate matter (PM), and combustible gas, is a largely

invisible health risk. Existing commercial solutions are either too expensive, closed-source, or limited to a single measurement type.

This project addresses that gap by combining nine sensors on a single node, connected to a local MQTT broker for real-time telemetry. The firmware is built on PlatformIO, ESP-IDF, and FreeRTOS, making use of four concurrent tasks that coordinate through a mutex-protected global state structure. Sensor data is published as JSON payloads and consumed by a companion Node.js dashboard that renders live charts via Chart.js and pushes updates to browsers via Socket.IO.

The current repository documents breadboard bring-up, firmware architecture, runtime characterisation, and the web-dashboard edge. The form-factor integration into an actual outlet housing is left as a future step.

## 2 System Context

### 2.1 Hardware

The sensor node is built around an ESP32 dual-core 240 MHz microcontroller (Espressif esp32dev target). It communicates with nine sensors over five distinct interfaces. Table 1

summarises the complete sensor inventory.

Table 1: Complete sensor inventory used by the ESP32 node.

Sensor | Measured quan-
tity
Physical value | Bus | Driver
SCD40 | CO2, T, RH | Concentration, temperature, humidity | 2C I | Direct ESP-IDF
SHT41 | Temperature, humidity | High-precision T & RH | 2C I | esp-idf-lib
SGP41 | VOC, NOx | Gas indices 0–500 (Sensirion algorithm) | I 2C | Custom + GIA
BMP280 | Pressure, tempera-ture | Atmospheric P & T | 2C I | esp-idf-lib
AS7341 | Light spectrum | 8-channel F1–F8 basic counts | I 2C | k0i05/esp_as7341
PMS7003 | Particulate matter | PM1.0, PM2.5, PM10 [µg/m³ ] | UART | Custom wrapper
MiCS-5524 | Combustible gas | Voltage [V], heuristic CO [ppm] | ADC | Custom
AS312 | PIR motion | Motion detected (boolean) | GPIO | Custom
INMP441 | Ambient noise | Sound pressure level [dB SPL] | 2S I | Custom DSP

Electrical Outlet IoT | 2 System Context

### 2.2 System actors and data paths

The system involves the following actors:

- Sensor node: ESP32 (esp32dev), firmware in src/ and lib/. Samples all sensors on software-

defined deadlines, aggregates readings into a shared in-memory state, and transmits them via Wi-Fi.

- Wi-Fi / TCP: the node connects as a Wi-Fi station; all MQTT traffic flows over a standard

TCP connection to the broker.

- MQTT broker: any standard broker (e.g. Mosquitto) reachable on the LAN. Credentials and

URI are configured in lib/config/include/app_config.h.

- Node.js dashboard: an optional server/ application that subscribes to all device topics and renders live charts in the browser via Socket.IO and Chart.js.
- Third-party consumers: any MQTT subscriber can access the JSON payloads independently of the dashboard.

### 2.3 MQTT topics

All publications follow the hierarchy devices/<device_id>/ where device_id is set by APP_DEV

ICE_ID:

- telemetry/environment (QoS 0) — full sensor snapshot: CO2, T, RH from SCD40 and SHT41, atmospheric pressure, VOC/NOx indices, PM1.0/2.5/10, 8-channel light array, gas

voltage and ppm, noise level in dB SPL. Published every 1 s.

- status/system (QoS 1, retain) — system health flags: system_ok, degraded_mode, wifi_co

nnected, mqtt_connected. Published every 10 s and immediately on reconnect.

- event/alarm (QoS 1) — event-driven alert: as312_alarm (motion), mics5524_alarm (gas threshold exceeded), co2_alarm_level (IDA-inspired 6-level classification). Published only on

the rising edge of each alarm flag.

### 2.4 Web dashboard

The companion dashboard runs on Node.js (server/public/server.js) and uses the express, m

qtt, socket.io, and dotenv packages. It subscribes to the wildcard patterns devices/+/teleme

try/environment, devices/+/status/system, and devices/+/event/alarm, merges incoming payloads into a per-device state object, and forwards it to all connected browsers in real time. Configuration is via a .env file (MQTT_BROKER_URL, optional credentials, PORT).

Electrical Outlet IoT | 3 Requirements

## 3 Requirements

Requirements are written from the user perspective and are traceable to implementation files.
The State column uses colour coding: | implemented | , | partial | , or | open | .

Table 2: System requirements and current implementation status.

ID | Requirement (user perspective) | State
R1 | The system shall boot, initialise all peripherals, create four FreeRTOS tasks, and reach a fully operational state without a fatal error within 20 s of power-on. | implemented
R2 | The system shall connect to the configured Wi-Fi network within 15 s; on disconnect it shall retry up to APP_WIFI_MAX_RETRY times automatically. | implemented
R3 | The system shall publish a JSON environment payload to the MQTT broker at least every 1 s and a system-status payload every 10 s when connected. | implemented
R4 | The system shall publish an alarm event payload on the rising edge of a motion or gas alarm, without missing edges caused by task jitter. | implemented
R5 | All concurrent accesses to g_device_state shall be serialised by a FreeRTOS mutex (g_device_state_mutex) with no unbounded blocking. | implemented
R6 | All nine integrated sensors shall be polled within their specified deadlines without one slow sensor blocking another. | implemented
R7 | The system shall report an estimated ambient noise level (noise_db) in dB SPL; absolute accuracy relative to a calibrated sound-level meter is not guaranteed without field calibration of INMP441_SPL_OFFSET_DB. | partial
R8 | Stack high-water mark and heap usage shall be logged and reported for all tasks over at least 10 minutes of continuous operation. | implemented
R9 | Automated unit tests shall cover MQTT payload builders and sensor supervision logic. | open
R10 | The system shall attempt automatic sensor restoration (re-initialisation and re-covery) after a detected sensor crash, with bounded retries and fault reporting if recovery fails. | open

Electrical Outlet IoT | 4 Design

## 4 Design

### 4.1 Boot sequence

At startup, app_main (in src/main.c) executes the following ordered steps. All critical steps

abort the system on failure; non-critical sensor failures are logged as warnings and allow the system to continue in degraded mode.

### 1. device_state_init() — zero-initialises g_device_state and creates the two FreeRTOS

mutexes (g_device_state_mutex and g_sensor_driver_mutex).

2. sensor_init_all() — initialises hardware peripherals in order: ADC unit 1, I²S channel, I²C

bus, UART 2, then each sensor driver. Critical peripherals abort on failure; sensors warn and

continue.

3. network_app_init() — initialises NVS, netif, Wi-Fi driver, and starts the connection; registers event handlers for WIFI_EVENT and IP_EVENT.

### 4. network_app_wait_until_connected(15000) — blocks up to 15 s waiting for APP_WIFI_CO

NNECTED_BIT; aborts if the bit is not set.

### 5. mqtt_app_start() — creates the ESP-IDF MQTT client, registers the event handler, and

starts the client task.

6. Task creation — xTaskCreate is called for each of the four tasks; any allocation failure aborts immediately.

Electrical Outlet IoT | 4 Design

### 4.2 FreeRTOS task architecture

The firmware is decomposed into four independent FreeRTOS tasks. All tasks use vTaskDelayUntil for deterministic loop periods and xSemaphoreTake / xSemaphoreGive for exclusive access to the

shared state. Table 3 summarises the static parameters.

Table 3: Static configuration of the four FreeRTOS tasks.

Task | Responsibility | Pri. | Stack (w) | Period
acquisition_task | Polls all sensors on individual software deadlines; writes measured values, validity flags, and fault flags into g_device_state under the mutex. | 2 | 4096 | 1000 ms
audio_task | DMA-reads one audio block from the INMP441 via I 2S, computes AC-RMS SPL, and updates noise_db in the shared state. | 2 | 4096 | 500 ms
comm_task | Snapshots the shared state and drives the MQTT pub-lish schedule: environment telemetry at 1 s, system status at 10 s, and alarm events on rising edge. | 3 | 4096 | 100 ms
system_task | Reads the shared state snapshot, evaluates per-sensor health checks (staleness, fault, validity) and alarm logic, then writes derived system flags back. | 4 | 4096 | 100 ms

Design pattern — local state before commit. Each task maintains a task-local state structure initialised to zero. Sensor readings and flags are written to this local copy first; only when a consistent update is ready is the mutex acquired and the global g_device_state updated in a single block-copy. This minimises the critical section duration and avoids partially-updated state being observed by other tasks.

### 4.3 Sensor polling intervals

Sensors inside acquisition_task are polled on independent software timers derived from xTaskG etTickCount(). Each sensor deadline is checked at every 1000 ms task tick; the sensor is read only when now - last_read ≥ interval. This means a single slow sensor (e.g. PMS7003) does not delay faster ones (e.g. AS312).

Table 4: Sensor polling intervals and interfaces used by the firmware.

Sensor | Physical quantity | Interface | Interval
AS312 | PIR motion | GPIO | 1000 ms
MiCS-5524 Combustible gas (CO heuristic) | ADC | 1000 ms
SGP41 | VOC index, NOx index | I²C | 1000 ms
AS7341 | 8-channel light spectrum | I²C | 1000 ms
SHT41 | Temperature, humidity | I²C | 2000 ms
BMP280 | Atmospheric pressure | I²C | 2000 ms
SCD40 | CO2, temperature, humidity | I²C | 2500 ms
PMS7003 | PM1.0, PM2.5, PM10 | UART | 5000 ms
INMP441 | Noise level (dB SPL) | I²S (audio_task) | 500 ms

Electrical Outlet IoT | 4 Design

### 4.4 System supervision and alarm logic

system_task implements two independent modules:
Health module (lib/health/): after a 45 s cold-start window, each sensor is checked for three conditions: (1) the validity flag is false, (2) the fault flag is true, or (3) the timestamp age exceeds a per-sensor timeout (45 s for all sensors). Any failing check sets degraded_mode = true

and the sensor-specific degraded_* flag.
Alarm module (lib/alarm/): three independent sub-checks evaluate (1) motion from the AS312 PIR, (2) gas concentration from MiCS-5524 against a 5000 ppm threshold, and (3) CO2 from SCD40 classified into six levels (Optimal / Good / Moderate / Poor / Very Poor / Critical)

following IDA and ASHRAE 62.1-inspired thresholds.

### 4.5 System context diagram

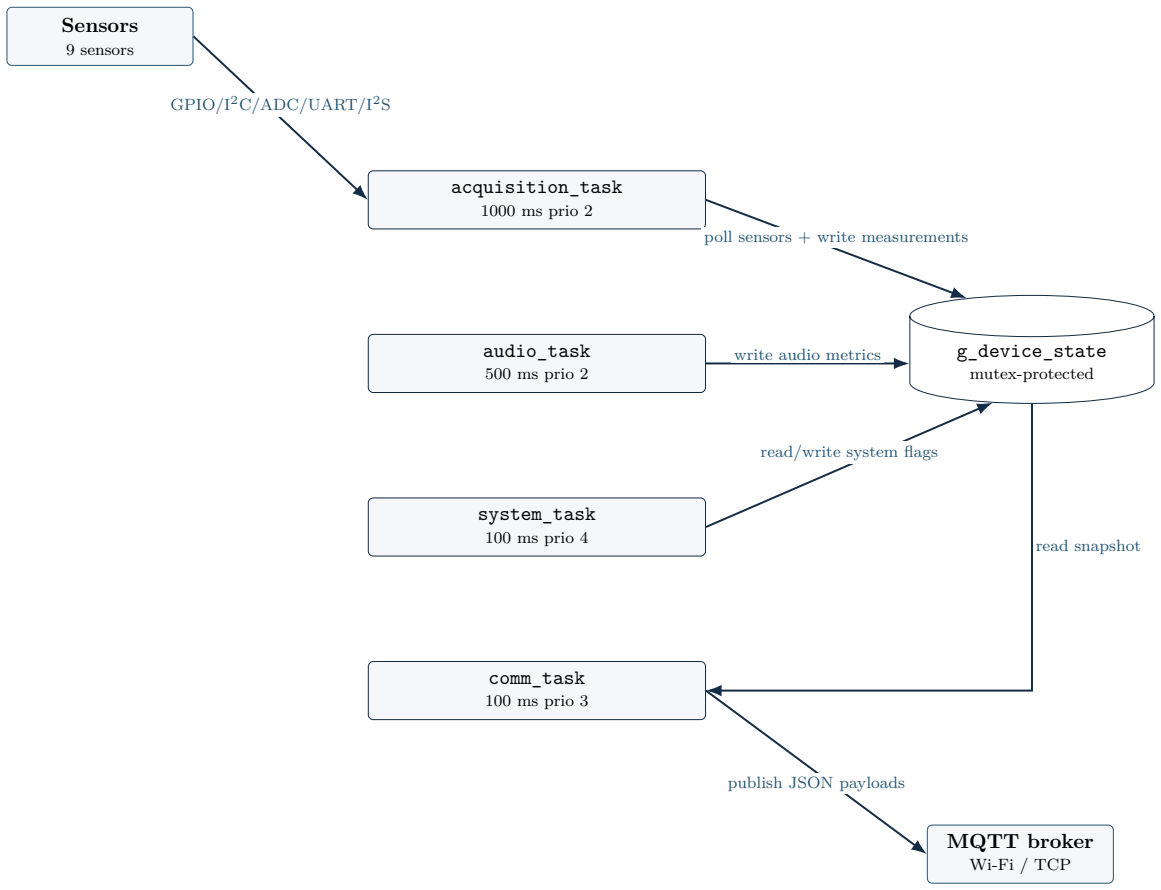
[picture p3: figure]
Sensors; 9 sensors; acquisition_task; 1000 ms prio 2; audio_task; 500 ms prio 2; system_task; 100 ms prio 4; comm_task; 100 ms prio 3; g_device_state; mutex-protected; MQTT broker; Wi-Fi / TCP; GPIO/I²C/ADC/UART/I²S; poll sensors + write measurements; write audio metrics; read/write system flags; read snapshot; publish JSON payloads

Figure 1: System context diagram showing sensors, FreeRTOS tasks, the mutex-protected shared state, and the MQTT broker used for publishing telemetry, status, and alarm messages.

Electrical Outlet IoT | 4 Design

### 4.6 UML task interaction diagram


Figure 2: UML activity/sequence diagram of the four FreeRTOS tasks and their interactions with g_device_state and the MQTT client.

### 4.7 Acquisition polling flow

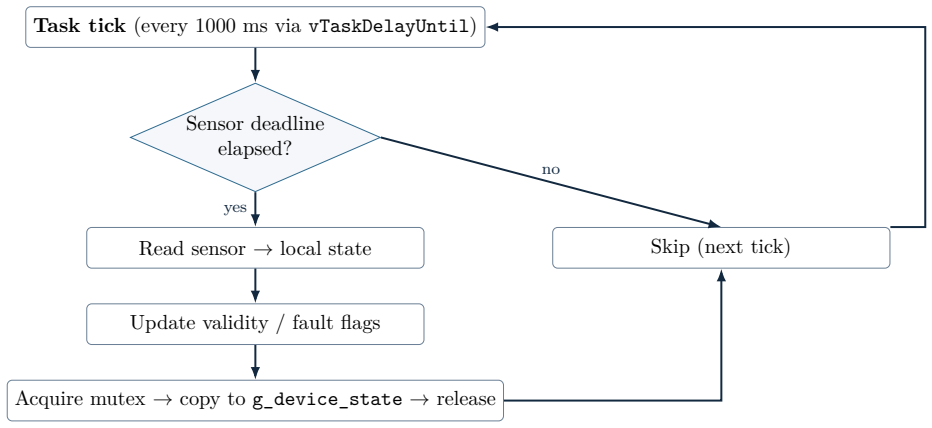
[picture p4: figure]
Sensor deadline elapsed?; Read sensor → local state; Update validity / fault flags; Skip (next tick); yes

Task tick (every 1000 ms via vTaskDelayUntil)

Acquire mutex → copy to g_device_state → release

Figure 3: Deadline-driven polling inside acquisition_task: each sensor has its own independent timer; skipped sensors do not block the loop.

Electrical Outlet IoT | 5 Runtime Statistics

## 5 Runtime Statistics

### 5.1 Methodology

Runtime measurements were collected from the ESP32 serial log using the helper functions

logTaskStackHeapUsage() and logTaskAlive(), defined in src/task_config.c. Each task logs its own stack high-water mark and the system-wide heap state every 10 s of wall-clock time. The measurements span approximately 10 minutes of continuous operation under normal conditions (all sensors active, Wi-Fi connected, MQTT publishing running). Raw data is archived

in raport/project_info/stack_heap.txt.
Stack usage percentage is computed as:

Stack Usage =

words used (high-water mark)
stack allocated (words) × 100%

where words used = allocated − high-water mark remaining (reported by uxTaskGetStackHighW aterMark(); 1 word = 4 bytes on ESP32).

### 5.2 Stack usage per task

Table 5: Measured stack usage per FreeRTOS task over the runtime window.

Task | Pri. | Stack | Stack used | Usage | Avg. CPU
| | alloc. (w) | (HWM, w) | (%) | (%)
acquisition_task | 2 | 4096 | 2532 | 61.8% | n/m
audio_task | 2 | 4096 | 2124 | 51.9% | n/m
comm_task | 3 | 4096 | 2812 | 68.7% | n/m
system_task | 4 | 4096 | 2352 | 57.4% | n/m

n/m = not measured (FreeRTOS runtime stats counter not enabled in this build).

Stack analysis. The highest consumer is comm_task (68.7%), followed by acquisition_task (61.8%). Even the worst case leaves 1284 words (5136 bytes) of free stack headroom on

comm_task, well above the ESP-IDF recommended minimum of 512 bytes. No stack overflow was observed during the measurement window. All four stacks are sized safely at the current feature set; if JSON payload building or additional sensors are added, comm_task should be monitored first.

Electrical Outlet IoT | 5 Runtime Statistics

### 5.3 Heap usage over time

The heap figures below are system-wide (MALLOC_CAP_8BIT pool, total ≈ 290 KB). “Min

free” is the all-time minimum free heap reported by heap_caps_get_minimum_free_size, which is the most conservative safety margin.

Table 6: System heap usage at three measurement windows.

Window | Used (B) | Free (B) | Min free (B) | Usage | Notes
∼10 s | 107 460 | 183 116 | 176 968 | 37.0% | Post-boot steady state
∼1 min | 107 452 | 183 124 | 176 968 | 37.0% | Stable; marginal drift
∼10 min | 107 432 | 183 144 | 176 968 | 37.0% | Stable baseline
Peak (transient) | 108 992 | 181 584 | 176 968 | 37.5% | Acquisition spike

Heap analysis. Heap usage is highly stable at approximately 37% of the total ≈290 KB pool, leaving a comfortable 63% free (≈183 KB) during steady-state operation. The minimumfree-ever figure of 176 968 B (≈173 KB) confirms that even transient allocation peaks (up to 108 992 B used, observed periodically during acquisition_task sensor reads) do not threaten memory safety. Importantly, the baseline heap usage decreased slightly over 10 minutes (from 107 460 B to 107 432 B), indicating that there are no measurable memory leaks over the

observation window.

Electrical Outlet IoT | 6 File Structure

## 6 File Structure

The repository follows the PlatformIO convention with a src/ entry point, a lib/ folder for reusable modules, and a top-level include/ for headers shared across tasks. Each library module lives in its own subdirectory with an include/ header folder and a src/ implementation folder, making cross-compilation units and Doxygen generation straightforward.

Table 7: Repository file structure and module responsibilities.

Path | Purpose
src/ | Application entry point (main.c) and the four FreeRTOS task implementations: acquisition_task.c, audio_task.c, comm_task.c, system_task.c. Also contains task_config.c (stack/heap logging helpers) and idf_component.yml (managed com-ponent manifest).
include/ | Shared task headers (*_task.h); task_config.h defining stack sizes, task priorities, sensor polling intervals, and MQTT publish cadences.
lib/config/ | app_config_template.h (Wi-Fi, MQTT, QoS, device ID constants) and esp32_pinout.h (GPIO/peripheral pin assignments).
lib/device_state/ | Global g_device_state struct and the two FreeRTOS mutexes; all sensor values, timestamps, validity/fault flags, and system flags.
lib/network/ | Wi-Fi station init (network_app.c): NVS, netif, event handlers, reconnect logic, and the connection-ready event group.
lib/mqtt/ | Four modules: mqtt_app (client lifecycle), mqtt_topic (topic string builders), mqtt_payload (JSON serialisers), mqtt_publish (high-level publish API).
lib/sensor_init/ | Peripheral bring-up: adc_init, i2s_init, uart_init (individual units), and sensor_init (orchestrates all).
lib/ (drivers) | One folder per sensor: scd40, sht41, sgp41, bmp280, as7341, pms7003, mics5524, as312, inmp441. Plus health (supervision), alarm (event logic), rgbled (status LED).
lib/sgp41/include/ | Also contains Sensirion’s BSD-3 Gas Index Algorithm header (sensirion_gas_index_algorithm.h).
server/ | Node.js dashboard: public/server.js (MQTT subscriber + Socket.IO relay), app.js, index.html, style.css, package.json.
scripts/ | update_clangd_toolchain.py: PlatformIO post-build hook that patches .clangd with the correct ESP-IDF include paths for IDE support.
platformio.ini | Build configuration: esp32dev target, ESP-IDF framework, 4 MB flash, 115200 baud monitor, post-build extra script.
raport/ | This report (raport.tex), the BFH template PDF, and project_info/ with raw measurement logs.

Electrical Outlet IoT | 7 User Manual

## 7 User Manual

Prerequisite: the ESP32 has already been flashed with the firmware. You need a Wi-Fi network and an MQTT broker (e.g. Mosquitto) reachable on the same LAN.

### 7.1 Step 1 — Configure credentials

Open lib/config/include/app_config.h and fill in your values:

#define APP_WIFI_SSID | "YourNetworkSSID"

#define APP_WIFI_PASSWORD | "YourNetworkPassword"

#define APP_MQTT_BROKER_URI | "mqtt://192.168.1.10" | // broker IP

#define APP_DEVICE_ID | "esp32_node_01" | // unique ID

Leave APP_MQTT_USERNAME and APP_MQTT_PASSWORD empty if your broker has no authentication. Rebuild and re-flash after editing this file.

### 7.2 Step 2 — Flash and monitor

From the repository root, run:

# Build, upload, and open serial monitor (115200 baud)

pio run -t upload && pio device monitor -b 115200

If the serial port is not detected automatically, add upload_port = /dev/ttyUSB0 (or the appro-

priate port) to platformio.ini.

### 7.3 Step 3 — Verify boot sequence

Watch the serial output. A successful startup prints, in order:

1. [MAIN] System booting...
2. [MAIN] Sensors initialized successfully
3. [MAIN] Wi-Fi connected successfully
4. [MAIN] Starting MQTT

### 5. MQTT_APP: MQTT client started

6. [MAIN] All tasks started

If any step fails, the system prints an error and calls abort(). Check credentials (app_config.h), broker reachability (ping from the same subnet), and GPIO wiring.

Electrical Outlet IoT | 7 User Manual

### 7.4 Step 4 — Subscribe to MQTT topics

Use any MQTT client to verify the data stream. Example with mosquitto_sub:

# All topics for this device

mosquitto_sub -h 192.168.1.10 -t "devices/esp32_node_01/#" -v

# Environment telemetry only

mosquitto_sub -h 192.168.1.10 \

-t "devices/esp32_node_01/telemetry/environment" -v

You should see a new JSON payload roughly every second on the environment topic.

### 7.5 Step 5 — Start the web dashboard (optional)

cd server

npm install | # first run only
cp .env.example .env | # create local config

Edit .env and set MQTT_BROKER_URL=mqtt://192.168.1.10 (and PORT if needed), then:

npm start

Open http://localhost:3000 (or the configured port) in a browser. Live charts for all sensor

channels update automatically via Socket.IO.

### 7.6 Troubleshooting

- Wi-Fi fails: verify SSID/password in app_config.h; check that the access point uses WPA2-

PSK.

- MQTT fails: ping the broker from the LAN; ensure APP_MQTT_BROKER_URI starts with mqtt:// and uses the correct IP and port (default 1883).
- Sensor missing from payload: check wiring against esp32_pinout.h; the degraded_mode flag in status/system will be true after 45 s if a sensor stops responding.
- Noise level seems wrong: the INMP441_SPL_OFFSET_DB constant in lib/inmp441/src/inm p441_w.c can be adjusted. Compare the reported noise_db against a calibrated sound-level meter in a known environment and set offset = L_meter - L_firmware.

Electrical Outlet IoT | 8 Version control

## 8 Version control

Table 8: Document revision history.

Ver. | Date | Description | Author
0.1 | 2026-03-18 | Initial RTOS template alignment; basic structure and task overview. | S. / A.
0.2 | 2026-03-21 | Sensor integration notes; first version of requirements table. | S. / A.
0.3 | 2026-04-06 | Architecture refresh: context diagram, acquisition flowchart, TODO metrics. | S. / A.
0.4 | 2026-04-06 | Full English report; layout refresh; MQTT/dashboard/scripts sync with repo. | S. / A.
0.5 | 2026-04-24 | Runtime statistics filled with measured stack/heap values from 10-min logs. | S. / A.
1.0 | 2026-04-24 | Final report: sensor table, analysis boxes, improved design section, UML diagram, extended user manual, troubleshooting guide. | S. / A.

Firmware and tools are licensed under the Apache 2.0 License unless noted otherwise in individual file headers. The Sensirion Gas Index Algorithm is licensed under BSD 3-Clause.

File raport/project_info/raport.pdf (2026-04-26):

# Title

## RTOS Project Work

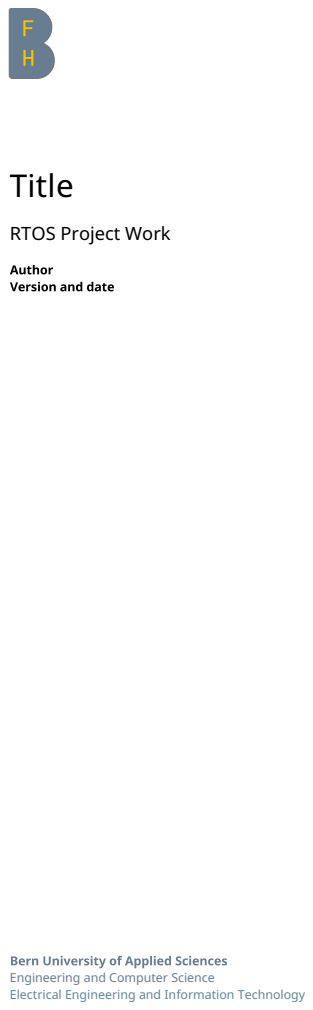
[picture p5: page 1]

Author
Version and date

Bern University of Applied Sciences
Engineering and Computer Science
Electrical Engineering and Information Technology

Berner Fachhochschule | Haute école spécialisée bernoise | Bern University of Applied Sciences | 2

## 1 Summary

[Give a very short summary of your application. Background, why?, what problem do you solve?]

## 2 System Context

[Provide a brief context of the whole system: hardware, other systems, databases. This is usually a simpler version of the context diagram but with more images. No specific diagram syntax required.]

## 3 Requirements

[Provide a set of short requirements. Write them from the user perspective and quantifiable.]

ID | Requirement | State
[open/
implemented/
rejected]

## 4 Design

[Add your design diagrams: context, C/DFD, UML] [If you create GUI, add GUI mockup here]

## 5 Runtime Statistics

Task | Priority | Stack Allocated | Stack Usage in % (high water mark)

(optional) Average
CPU usage in %
Time | Heap Usage in B
~ 10s runtime
~ 1min runtim
~ 10min runtime

## 6 File Structure

[Give an overview of your files in your project with a short description]

Berner Fachhochschule | Haute école spécialisée bernoise | Bern University of Applied Sciences | 3

## 7 User Manual

[Assume the microcontroller is programmed. What must the user do to use your application. Use simple instructions and pictures, ~1 page]

## 8 Version control

Version | Date | Description | Author
0.1 | 26.02.2013 | Et ut aut isti | Peter Muster
0.2 | 13.03.2013 | Et ut aut isti | Anna Meier
1.0 | 21.05.2013 | Et ut aut isti | Peter Muster

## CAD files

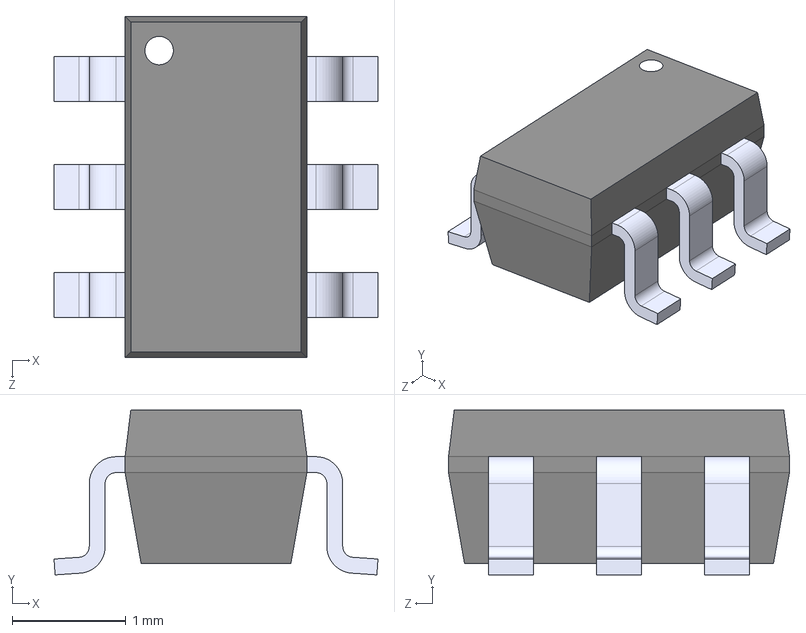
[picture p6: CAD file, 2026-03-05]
circuit_pcb/lib_component/AP7312-1833W6-7/AP7312-1833W6-7.step
2.85 x 1.45 x 3.00 mm

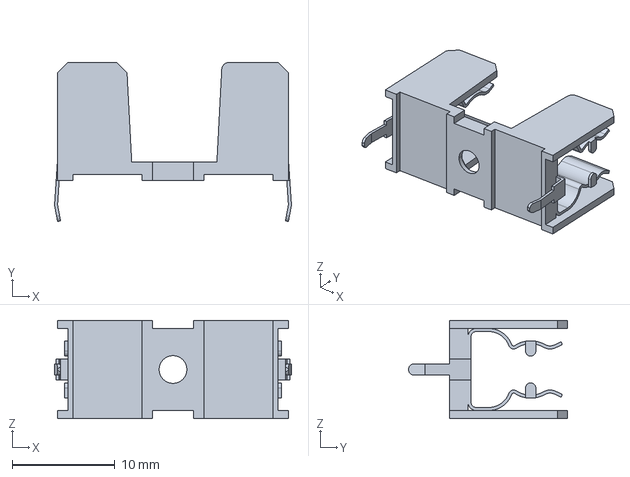
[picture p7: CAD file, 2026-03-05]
circuit_pcb/lib_component/LIB_0031.8201.G/0031.8201.G/3D/0031.8201.G.stp
23.1 x 15.5 x 9.60 mm

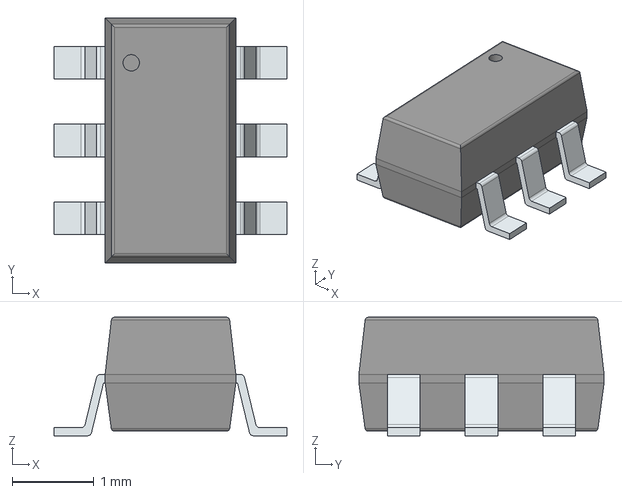
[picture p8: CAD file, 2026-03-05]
circuit_pcb/lib_component/LIB_AP7312-1828W6-7/AP7312-1828W6-7/3D/AP7312-1828W6-7.stp
2.85 x 3.00 x 1.45 mm
PinsArrayLR

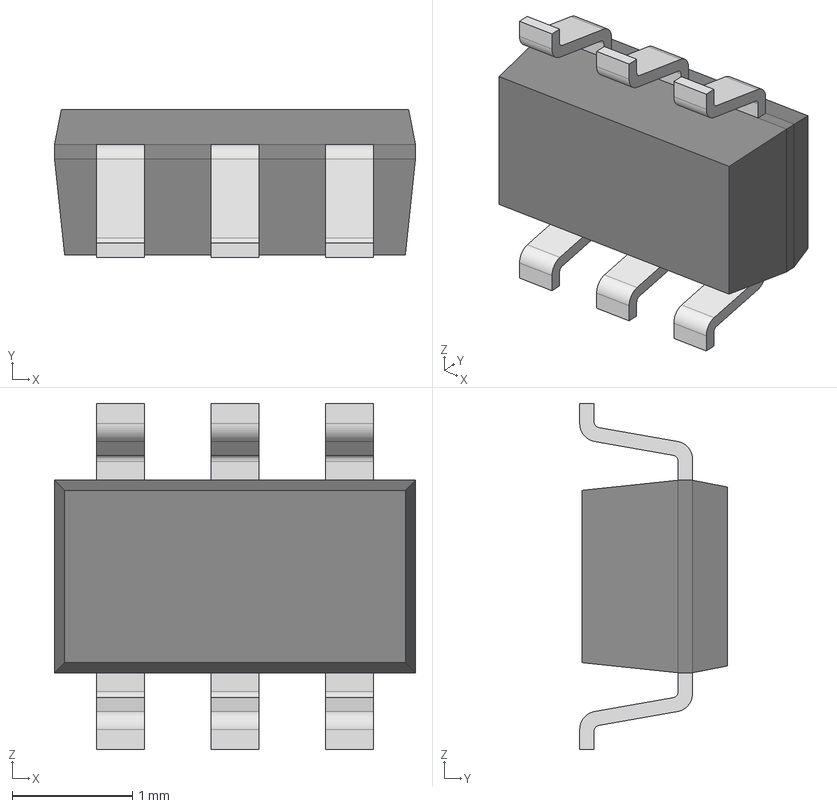
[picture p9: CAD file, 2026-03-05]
circuit_pcb/lib_component/LIB_AP7312-1833W6-7/AP7312-1833W6-7/3D/AP7312-1833W6-7.stp
3.00 x 1.23 x 2.88 mm

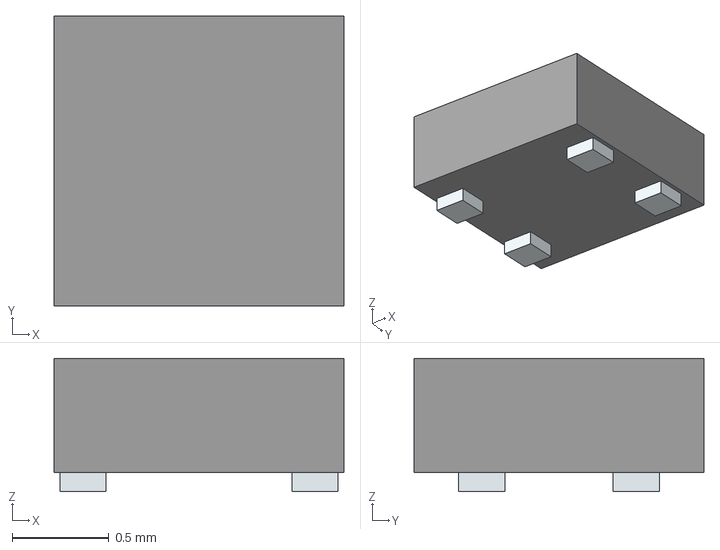
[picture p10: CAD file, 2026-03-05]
circuit_pcb/lib_component/LIB_SHT41A-AW1B-R2/SHT41A-AW1B-R2/3D/SHT41A-AW1B-R2.stp
1.50 x 1.50 x 0.69 mm
Pins

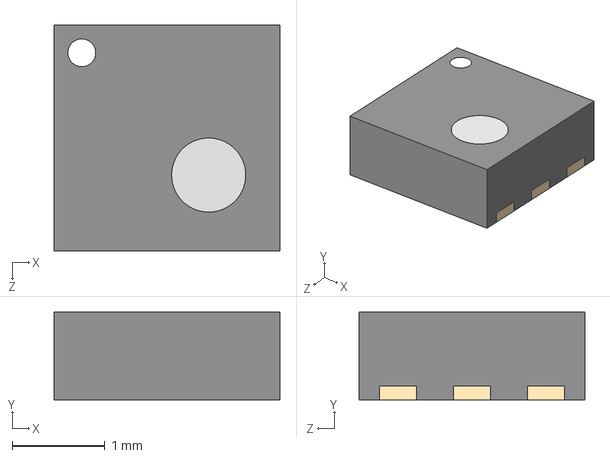
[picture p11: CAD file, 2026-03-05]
circuit_pcb/lib_component/SGP41-D-R4/SGP41-D-R4.step
2.44 x 0.95 x 2.44 mm

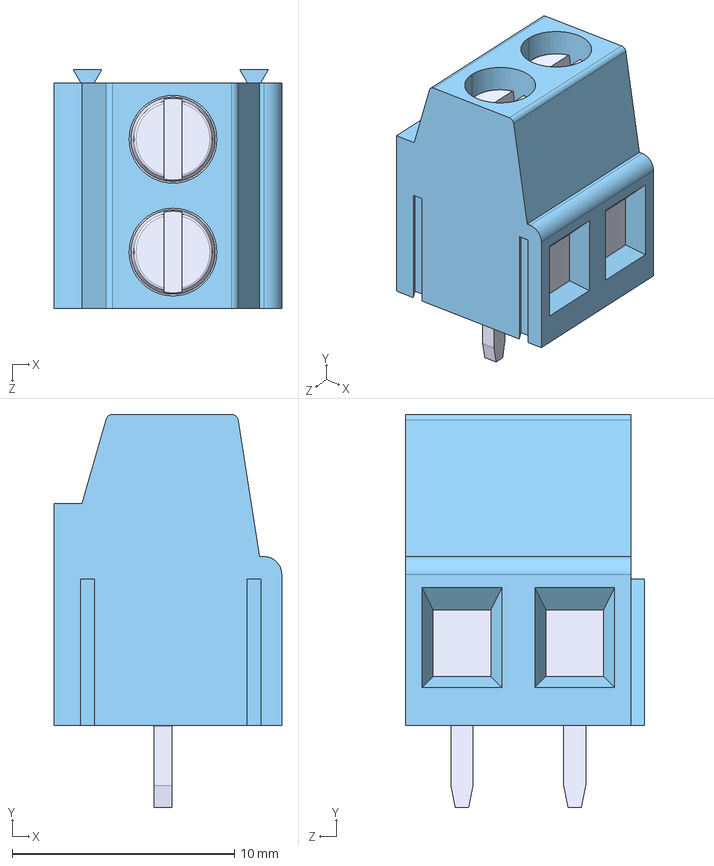
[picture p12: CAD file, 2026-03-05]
circuit_pcb/lib_component/TB007-508-02BE/TB007-508-02BE.step
10.2 x 17.7 x 10.8 mm

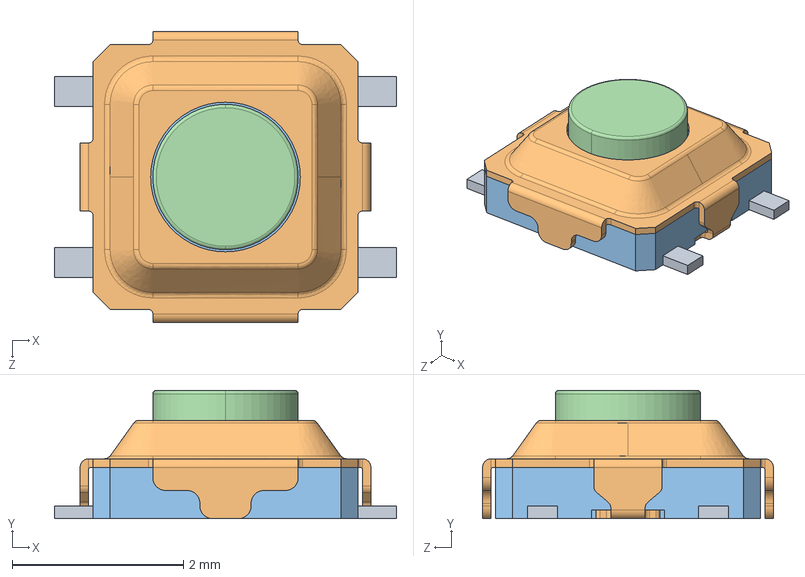
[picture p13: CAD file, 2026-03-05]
circuit_pcb/lib_component/TS21-34-035-BK-260-SMT-TR/TS21-34-035-BK-260-SMT-TR.step
4.00 x 1.50 x 3.40 mm

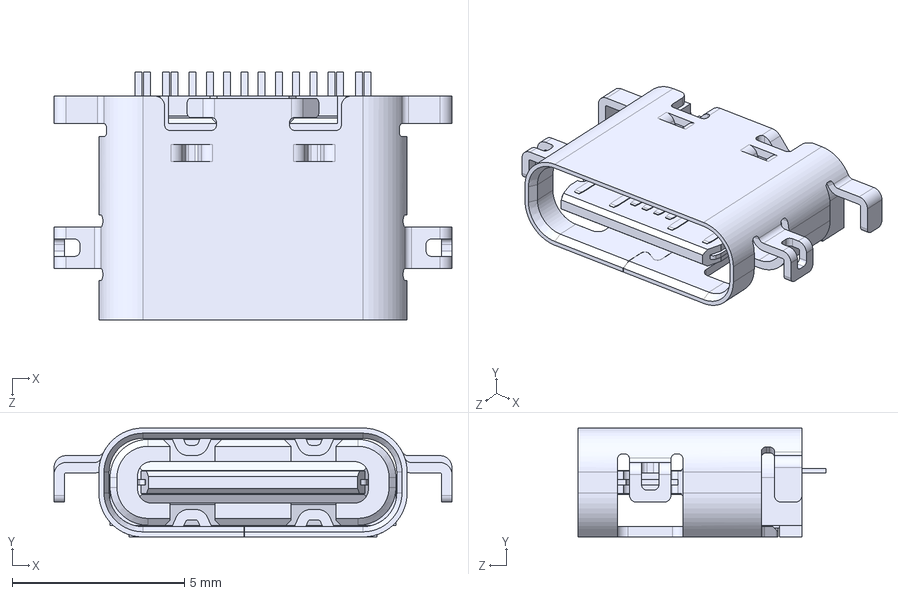
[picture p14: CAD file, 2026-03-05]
circuit_pcb/lib_component/UJ20-C-H-G-MSMT-4-P16-TR/UJ20-C-H-G-MSMT-4-P16-TR.step
11.5 x 3.16 x 7.20 mm

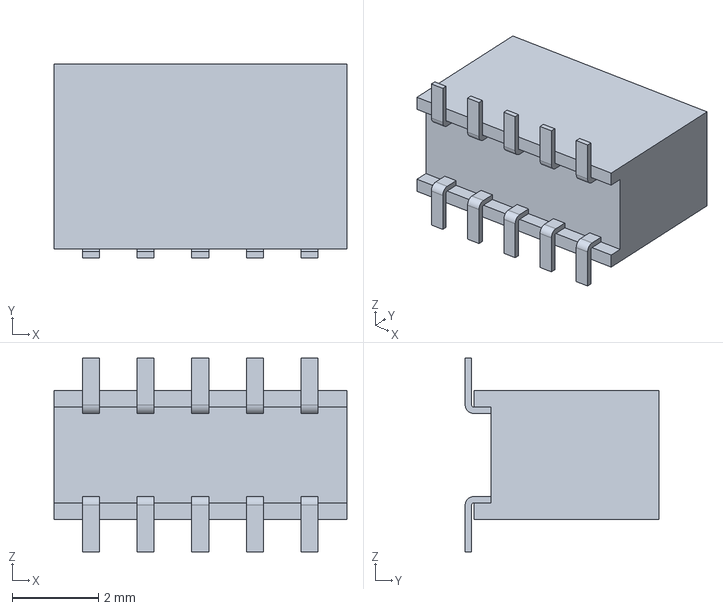
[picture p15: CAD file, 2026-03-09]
circuit_pcb/lib_component/20021321-00010C4LF/20021321-00010C4LF.step
6.81 x 4.50 x 4.50 mm

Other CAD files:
circuit_pcb/lib_component/LIB_0031.8201.G/0031.8201.G/DEHDL/0031.8201.g/chips/chips.prt
circuit_pcb/lib_component/LIB_AP7312-1828W6-7/AP7312-1828W6-7/Allegro/sot95p285x145-6n.psm
circuit_pcb/lib_component/LIB_AP7312-1828W6-7/AP7312-1828W6-7/DEHDL/ap7312_1828w6_7/chips/chips.prt
circuit_pcb/lib_component/LIB_AP7312-1833W6-7/AP7312-1833W6-7/Allegro/sop95p285x145-6n.psm
circuit_pcb/lib_component/LIB_AP7312-1833W6-7/AP7312-1833W6-7/DEHDL/ap7312_1833w6_7/chips/chips.prt
circuit_pcb/lib_component/LIB_SHT41A-AW1B-R2/SHT41A-AW1B-R2/Allegro/sht41aaw1br2.psm
circuit_pcb/lib_component/LIB_SHT41A-AW1B-R2/SHT41A-AW1B-R2/DEHDL/sht41a_aw1b_r2/chips/chips.prt

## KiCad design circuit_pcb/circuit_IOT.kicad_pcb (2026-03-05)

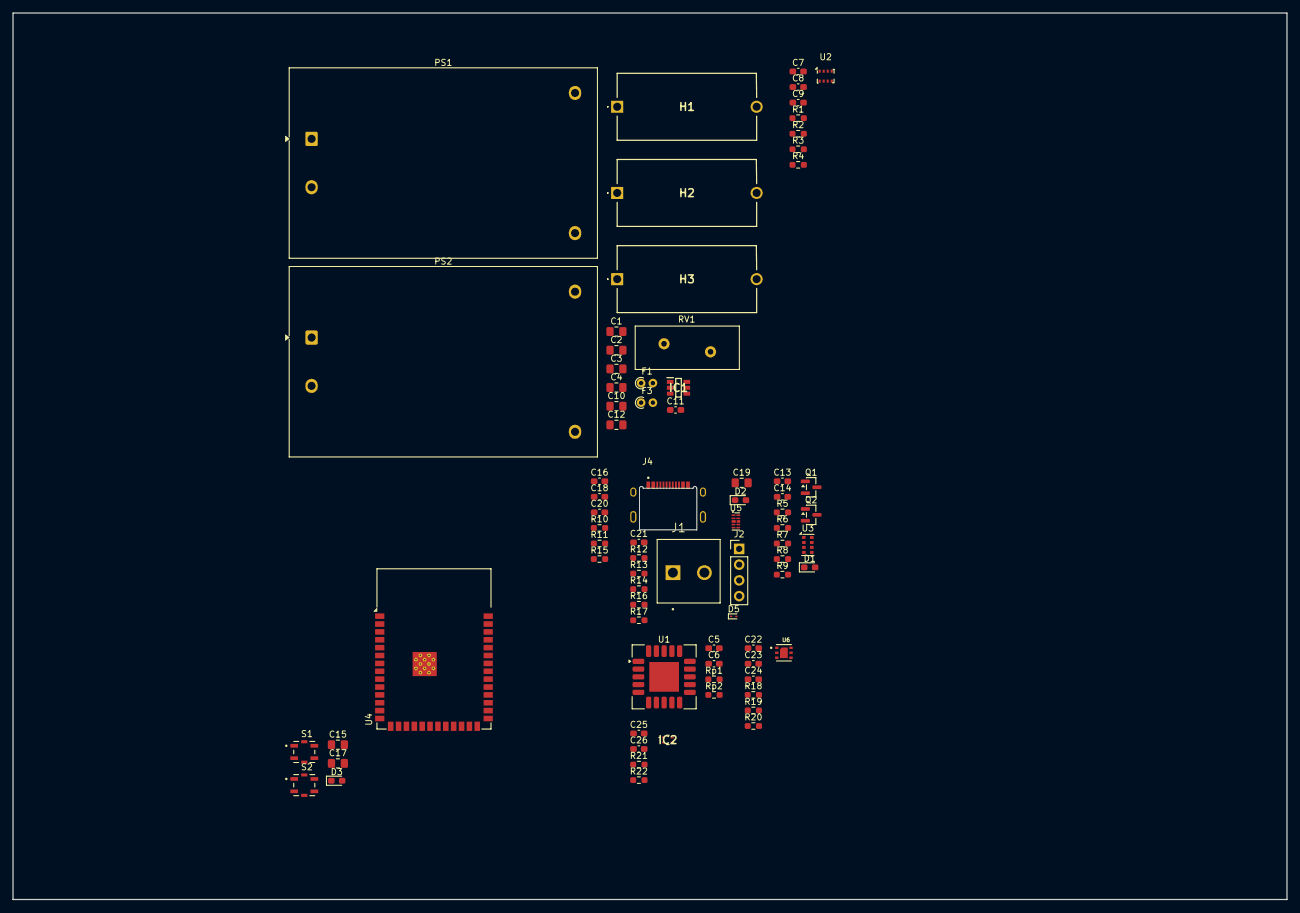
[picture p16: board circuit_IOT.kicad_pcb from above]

Board: 2 copper layers, 205.5 x 143.0 mm, 77 parts (0 on the bottom side), 36 nets, no tracks yet.

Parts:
C1, C2, C10, C12, C17, C19: 10uF; C_0805_2012Metric_Pad1.18x1.45mm_HandSolder
C3, C4, C15: 22uF; C_0805_2012Metric_Pad1.18x1.45mm_HandSolder
C5, C7, C8, C13, C16, C20, C21, C24, C26: 100nF; C_0603_1608Metric_Pad1.08x0.95mm_HandSolder
C6, C9, C14, C18, C22, C23, C25: 1uF; C_0603_1608Metric_Pad1.08x0.95mm_HandSolder
C11: 10uF; C_0603_1608Metric_Pad1.08x0.95mm_HandSolder
D1, D2, D3: LED; D_0603_1608Metric_Pad1.05x0.95mm_HandSolder
D5: SZESD9B5.0ST5G; D_SOD-923
F1: Fuse: Thermal Fuse 3.3V module; R_Axial_DIN0204_L3.6mm_D1.6mm_P1.90mm_Vertical
F3: Fuse: Thermal Fuse 5V module; R_Axial_DIN0204_L3.6mm_D1.6mm_P1.90mm_Vertical
H1, H2, H3: 0031.8201.G; 00318201G
IC1: AP7312-1833W6-7; SOP95P285X145-6N
IC2: SHT41A-AW1B-R2; SHT41AAW1BR2
J1: TB007-508-02BE; CUI_TB007-508-02BE
J2: Conn_01x04; PinHeader_1x04_P2.54mm_Vertical
J4: UJ20-C-H-G-MSMT-4-P16-TR; SAMESKY_UJ20-C-H-G-MSMT-4-P16-TR
PS1: HLK-10M05; Converter_ACDC_Hi-Link_HLK-10Mxx
PS2: HLK-10M03; Converter_ACDC_Hi-Link_HLK-10Mxx
Q1, Q2: BSS138; SOT-23
R1, R2, R3, R4, R5, R6, R7, R8, R9, R11, R19, R20, R21, R22: 10K; R_0603_1608Metric_Pad0.98x0.95mm_HandSolder
R10, R12, R13: 5.1K; R_0603_1608Metric_Pad0.98x0.95mm_HandSolder
R14, R15: 5K; R_0603_1608Metric_Pad0.98x0.95mm_HandSolder
R16, R17: 22; R_0603_1608Metric_Pad0.98x0.95mm_HandSolder
R18: 4.7; R_0603_1608Metric_Pad0.98x0.95mm_HandSolder
RV1: Varistor; RV_Disc_D16.5mm_W6.7mm_P7.5mm
Rp1, Rp2: 10K; R_0603_1608Metric_Pad0.98x0.95mm_HandSolder
S1, S2: TS21-34-035-BK-260-SMT-TR; SW_TS21-34-035-BK-260-SMT-TR
U1: SCD40-D-R2; Sensirion_SCD4x-1EP_10.1x10.1mm_P1.25mm_EP4.8x4.8mm
U2: BMP280; Bosch_LGA-8_2x2.5mm_P0.65mm_ClockwisePinNumbering
U3: AS7341DLG; AMS_OLGA-8_2x3.1mm_P0.8mm
U4: ESP32-S3-WROOM-1
U5: D3V3XA4B10LP; Diodes_UDFN-10_1x2.5mm_P0.5mm
U6: SGP41-D-R4; XDCR_SGP41-D-R4

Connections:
1.8V: C12.1, C13.1, C14.1, IC1.6 (OUT1), Q1.1 (G), Q2.1 (G), R8.1, R9.1, U3.1 (VDD)
3.3V: C2.1, C4.1, C5.1, C6.1, C7.1, C8.1, C9.1, C10.1, C15.1, C16.1, C17.1, C23.1, C24.1, C25.1, C26.1, D1.2 (A), H3.2, IC1.3 (EN2), IC1.4 (EN1), IC1.5 (IN), IC2.3 (VDD), J2.3, R2.1, R3.1, R4.1, R5.1, R6.1, R7.1, R10.1, R11.1, R15.1, R18.1, R19.1, R20.1, R21.1, R22.1, Rp1.1, Rp2.1, U1.7 (VDD), U1.19 (VDD), U2.6 (VDDIO), U2.8 (VDD), U4.2 (3V3), U6.5 (VDDH)
5V: C1.1, C3.1, H2.2
AP3.3V: C11.1, IC1.1 (OUT2)
BOOT: S2.2, U4.27 (IO0)
CSB_BMP280: R3.2, U2.2 (CSB)
D+: R17.2, U4.14 (USB_D+), U5.1, U5.10 (NC)
D-: R16.2, U4.13 (USB_D-), U5.2, U5.9 (NC)
EN: S1.2, U4.3 (EN)
GND: C1.2, C2.2, C3.2, C4.2, C5.2, C6.2, C7.2, C8.2, C9.2, C10.2, C11.2, C12.2, C13.2, C14.2, C15.2, C16.2, C17.2, C18.2, C19.2, C20.2, C21.2, C22.2, C23.2, C24.2, C25.2, C26.2, D2.1 (K), D3.1 (K), D5.1 (A1), IC1.2 (GND), IC2.4 (VSS), J2.4, J4.A1_B12 (GND), J4.B1_A12 (GND), J4.SH1 (SHIELD), J4.SH2 (SHIELD), J4.SH3 (SHIELD), J4.SH4 (SHIELD), PS1.3 (-Vout), PS2.3 (-Vout), R1.2, R12.2, R13.2, S1.3, S1.4, S2.3, S2.4, U1.6 (GND), U1.20 (GND), U1.21 (GND), U2.1 (GND), U2.7 (GND), U3.3 (GND), U3.5 (PGND), U4.1 (GND), U4.40 (GND), U4.41 (GND), U5.3 (VSS), U5.8 (VSS), U6.2 (VSS), U6.4 (N/A), U6.7 (EXP)
L_230V: J1.1, PS1.1 (AC/L), PS2.1 (AC/L), RV1.1
N_230V: H1.2, J1.2
unnamed: C18.1, R11.2, S1.1
unnamed: C20.1, R10.2, S2.1
unnamed: D1.1 (K), U3.4 (LDR)
unnamed: D2.2 (A), R14.2
unnamed: D3.2 (A), R15.2
unnamed: F1.1, F3.2
unnamed: F3.1, H1.1
unnamed: J4.A5 (CC1), R13.1
unnamed: J4.B5 (CC2), R12.1
unnamed: J4.A7 (DN1), J4.B7 (DN2), R16.1
unnamed: J4.A6 (DP1), J4.B6 (DP2), R17.1
unnamed: H2.1, PS1.4 (+Vout)
unnamed: F1.2, PS1.2 (AC/N), PS2.2 (AC/N), RV1.2
unnamed: H3.1, PS2.4 (+Vout)
unnamed: R5.2, U3.7 (INT)
unnamed: C22.1, R18.2, U6.1 (VDD)
RXD0: J2.2, U4.36 (RXD0)
SCL: IC2.2 (SCL), Q2.2 (S), R2.2, R6.2, R20.2, R21.2, Rp1.2, U1.9 (SCL), U2.4 (SCK), U6.6 (SCL)
SCL18_AS7341: Q2.3 (D), R9.2, U3.2 (SCL)
SDA: IC2.1 (SDA), Q1.2 (S), R4.2, R7.2, R19.2, R22.2, Rp2.2, U1.10 (SDA), U2.3 (SDI), U6.3 (SDA)
SDA18_AS7341: Q1.3 (D), R8.2, U3.8 (SDA)
SDO_BMP280: R1.1, U2.5 (SDO)
TXD0: J2.1, U4.37 (TXD0)
VBUS: C19.1, C21.1, D5.2 (A2), J4.A4_B9 (VBUS), J4.B4_A9 (VBUS), R14.1

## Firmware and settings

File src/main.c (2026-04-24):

/*
 * Copyright 2026 Simone Pelascini and Aurélien Bollin
 *
 * Licensed under the Apache License, Version 2.0 (the "License");
 */

/**
 * @file main.c
 * @brief Application entry point: peripheral init, Wi-Fi, MQTT, and FreeRTOS task creation.
 */

#include "mqtt_app.h"
#include "network_app.h"
#include "sensor_init.h"
#include "esp_log.h"
#include "esp_check.h"
#include "adc_init.h"
#include "uart_init.h"
#include "i2s_init.h"

#include <stdint.h>
#include <stdbool.h>

#include "freertos/FreeRTOS.h"
#include "freertos/task.h"

#include "task_config.h"
#include "acquisition_task.h"
#include "audio_task.h"
#include "system_task.h"
#include "comm_task.h"
#include "device_state.h"

static const char *TAG = "[MAIN]";

void app_main(void)
{
    ESP_LOGI(TAG, "System booting...");

    esp_log_level_set("*", ESP_LOG_INFO);

    device_state_init();

    ESP_LOGI(TAG, "Initializing sensors");
    if (sensor_init_all() != ESP_OK)
    {
        ESP_LOGE(TAG, "Failed to initialize sensors");
        abort();
    }
    else
    {
        ESP_LOGI(TAG, "Sensors initialized successfully");
    }

    ESP_LOGI(TAG, "Initializing device state mutex");
    if (g_device_state_mutex == NULL || g_sensor_driver_mutex == NULL)
    {
        ESP_LOGE(TAG, "Failed to create device_state or sensor driver mutex");
        abort();
    }
    else
    {
        ESP_LOGI(TAG, "Device state mutex created successfully");
    }

    ESP_LOGI(TAG, "Initializing network");
    if (!network_app_init())
    {
        ESP_LOGE(TAG, "Network initialization failed");
        abort();
    }
    else
    {
        ESP_LOGI(TAG, "Network initialized successfully");
    }

    ESP_LOGI(TAG, "Waiting for Wi-Fi connection");
    if (!network_app_wait_until_connected(15000))
    {
        ESP_LOGE(TAG, "Wi-Fi not connected, MQTT will not start");
        abort();
    }
    else
    {
        ESP_LOGI(TAG, "Wi-Fi connected successfully");
    }

    ESP_LOGI(TAG, "Starting MQTT");
    mqtt_app_start();

    ESP_LOGI(TAG, "Creating tasks");

    // Acquisition task
    if (xTaskCreate(acquisition_task,
        "acquisition_task",
        STACK_ACQUISITION_WORDS,
        NULL,
        ACQUISITION_TASK_PRIORITY,
        NULL) != pdPASS)
    {
        ESP_LOGE(TAG, "Failed to create acquisition_task");
        abort();
    }
    else
    {
        ESP_LOGI(TAG, "Acquisition task created");
    }

    // Audio task
    if(xTaskCreate(audio_task, 
       "audio_task",
       STACK_AUDIO_WORDS,
       NULL,
       AUDIO_TASK_PRIORITY,
       NULL) != pdPASS)
    {
        ESP_LOGE(TAG, "Failed to create audio_task");
        abort();
    }
    else
    {
        ESP_LOGI(TAG, "Audio task created");
    }

    // Comm task
    if(xTaskCreate(comm_task, 
       "comm_task",
       STACK_COMM_WORDS,
       NULL,
       COMM_TASK_PRIORITY,
       NULL) != pdPASS)
    {
        ESP_LOGE(TAG, "Failed to create comm_task");
        abort();
    }
    else
    {
        ESP_LOGI(TAG, "Comm task created");
    }

    // System task
    if(xTaskCreate(system_task, 
       "system_task",
       STACK_SYSTEM_WORDS,
       NULL,
       SYSTEM_TASK_PRIORITY,
       NULL) != pdPASS)
    {
        ESP_LOGE(TAG, "Failed to create system_task");
        abort();
    }
    else
    {
        ESP_LOGI(TAG, "System task created");
    }

    ESP_LOGI(TAG, "All tasks started");
}

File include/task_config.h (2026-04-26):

/*
 * Copyright 2026 Simone Pelascini and Aurélien Bollin
 *
 * Licensed under the Apache License, Version 2.0 (the "License");
 */

/**
 * @file task_config.h
 * @brief FreeRTOS task stacks, priorities, periods, and stack-usage logging helper.
 */

#ifndef __TASK_CONFIG_H__
#define __TASK_CONFIG_H__

#include <stdint.h>
#include "freertos/FreeRTOS.h"
#include "freertos/task.h"
#include "esp_log.h"

/**
 * @name Task stack sizes (FreeRTOS words; 1 word = 4 bytes on ESP32)
 * @{
 */
#define STACK_ACQUISITION_WORDS     4096    /**< Acquisition task stack [words]. */
#define STACK_AUDIO_WORDS           4096    /**< Audio / I2S task stack [words]. */
#define STACK_SYSTEM_WORDS          4096    /**< System supervision task stack [words]. */
#define STACK_COMM_WORDS            4096    /**< MQTT / network task stack [words]. */
/** @} */

/**
 * @name Task priorities (higher value = higher priority)
 * @{
 */
#define ACQUISITION_TASK_PRIORITY   2
#define AUDIO_TASK_PRIORITY         2
#define SYSTEM_TASK_PRIORITY        4
#define COMM_TASK_PRIORITY          3
/** @} */

/**
 * @name Sensor polling intervals (milliseconds)
 * @{
 */
#define AS312_INTERVAL_MS      1000
#define MICS5524_INTERVAL_MS   1000
#define SGP41_INTERVAL_MS      1000
#define SHT41_INTERVAL_MS      2000
#define BMP280_INTERVAL_MS     2000
#define AS7341_INTERVAL_MS     1000
#define SCD40_INTERVAL_MS      2500 // poll faster than the 5 s cycle to catch the data-ready window
#define PMS7003_INTERVAL_MS    5000
/** @} */

/**
 * @name mqtt polling intervals (milliseconds)
 * @{
 */
 #define MQTT_ENVIRONMENT_INTERVAL_MS 1000
 #define MQTT_SYSTEM_INTERVAL_MS 10000
 /** @} */

/**
 * @name Application task loop periods (milliseconds)
 * @{
 */
#define ACQUISITION_TASK_INTERVAL_MS 1000
#define AUDIO_TASK_INTERVAL_MS 500
#define SYSTEM_TASK_INTERVAL_MS 100
#define COMM_TASK_INTERVAL_MS 100
/** @} */

/**
 * @name Stack/heap log ceilings (one log every LOG_STACK_PERIOD_MS)
 *
 * ceiling = LOG_STACK_PERIOD_MS / TASK_INTERVAL_MS
 * @{
 */
#define LOG_STACK_PERIOD_MS             10000UL
#define LOG_CEILING_ACQUISITION  (LOG_STACK_PERIOD_MS / ACQUISITION_TASK_INTERVAL_MS)  /**< 10  */
#define LOG_CEILING_AUDIO        (LOG_STACK_PERIOD_MS / AUDIO_TASK_INTERVAL_MS)         /**< 20  */
#define LOG_CEILING_SYSTEM       (LOG_STACK_PERIOD_MS / SYSTEM_TASK_INTERVAL_MS)        /**< 100 */
#define LOG_CEILING_COMM         (LOG_STACK_PERIOD_MS / COMM_TASK_INTERVAL_MS)          /**< 100 */
/** @} */

/** @brief Log tag string used for verbose sensor debug lines. */
#define TAG_DEBUG "[DEBUG]"

/**
 * @brief Log stack and heap usage for the calling task every @p ceiling invocations.
 *
 * @param[in,out] counter Incremented each call; logs when @c (++*counter % ceiling) == 0 (avoid @p ceiling == 0).
 * @param[in] ceiling Period between log lines (e.g. 10 or 50 depending on task loop rate).
 * @param[in] TAG Reserved for call-site consistency; current implementation logs with @c TAG_DEBUG.
 * @param[in] task_stack_size Total stack size of this task in words (for "used" display).
 */
void logTaskStackHeapUsage(uint32_t *counter, uint32_t ceiling, const char *TAG, UBaseType_t task_stack_size);

/**
 * @brief Periodic “task alive” heartbeat at @c ESP_LOGI level using the given @p TAG.
 *
 * @param[in] TAG ESP-IDF log tag for the message (visible at default @c INFO level).
 * @param[in,out] alive_counter Incremented each call; logs when @c (++*alive_counter % ceiling) == 0.
 * @param[in] ceiling Number of calls between two “Task alive” lines.
 *
 * @note @p ceiling must not be 0.
 * @note First log occurs when the counter reaches @p ceiling, not on the first call (after increment).
 */
void logTaskAlive(const char *TAG, uint32_t *alive_counter, uint32_t ceiling);


#endif // __TASK_CONFIG_H__

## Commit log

2026-03-05 [new] master: first commit
    [0031.8201.G.SchLib, 0031.8201.G.stp, 00318201G.PcbLib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]
2026-03-05 [new] work: new readme.md and checklist of components required for the first prototype
    [component.csv]
2026-03-09 [new] main.c: delete mq7 sensor
2026-03-09 [new] readme.md: v1.0 mermaid layout of prototype
2026-03-09 [new] readme.md: v1.1 mermaid layout of prototype
2026-03-09 [new] readme.md: v1.2 mermaid layout of prototype
2026-03-09 [new] readme.md: v1.3 mermaid layout of prototype
2026-03-09 [new] readme.md: v1.4 mermaid layout of prototype
2026-03-09 [new] circuit pcb: added PMS7003
    [20021321-00010C4LF.step, Change Log.xlsx, PMS7003 sensor adapter 3D.step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]
2026-03-09 [new] readme.md: added led rgb status
2026-03-10 [new] clean all the project and I've prepared all the folders
    [Change Log.xlsx, PMS7003 sensor adapter 3D.step, PMS7003 sensor adapter BOM.csv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]
2026-03-11 [new] include: cleaned this folder
    [component.csv]
2026-03-11 [new] device_state: new file with mutex and global structure
2026-03-18 [new] network: integrated in code and corrected some bug
    [main.c]
2026-03-18 [new] gitignore: added prototype of latex raport
2026-03-18 [new] components: new description
    [component.csv]
2026-03-19 [new] test esp32 + server -> work
2026-03-19 [new] csv component updated with pinout
    [component.csv]
2026-03-20 [new] pinout updated
    [component.csv]
2026-03-20 [new] sensor init: new files
2026-03-21 [new] micd5524: v1.2 adc and calibration
2026-03-21 [bug] bug in scd40 drivers
    [task_config.h]
2026-03-23 [new] update component pinout
    [component.csv]
2026-03-23 [new] pinout esp32 updated
2026-03-23 [new] fix scd40 and add new pinout for pms7003
    [component.csv]
2026-03-23 [new] pms7003 driver added and works
2026-03-23 [new] all sensors in acquisition task work
2026-03-24 [new] first version of drivers for inmp441
2026-03-24 [BUG] new system of restore, introduce a bug!
    [main.c]
2026-03-26 [bug] still have a bug in healt restore
    [main.c]

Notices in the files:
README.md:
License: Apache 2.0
